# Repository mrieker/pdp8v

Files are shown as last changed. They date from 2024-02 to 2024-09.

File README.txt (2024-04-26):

Vacuum tube implementation of PDP-8/V using a Raspberry PI for memory and I/O devices.

Website:  https://www.outerworldapps.com/pdp8v

To generate PCBs (can be run from a PC or a RasPI):
    cd netgen
    make
    cd ../modules
    make   << generates unrouted ACL, ALU, MA, PC, RPI, SEQ boards

    open each of the above in its directory in the kicads directory
    ... and route route route!

Or use these routed PCBs that match this rev:
    https://www.outerworldapps.com/pdp8v/acl-2024-04-15.tgz
    https://www.outerworldapps.com/pdp8v/alu-2024-04-15.tgz
    https://www.outerworldapps.com/pdp8v/ma-2024-04-15.tgz
    https://www.outerworldapps.com/pdp8v/pc-2024-04-15.tgz
    https://www.outerworldapps.com/pdp8v/rpi-2024-04-15.tgz
    https://www.outerworldapps.com/pdp8v/seq-2024-04-15.tgz

To run a PDP-8 program (from a RasPI plugged into RPI board):
    cd driver
    make raspictl.`uname -m`
    ./raspictl -binloader <name-of-some-bin-format-file>
            or -rimloader <name-of-some-rim-format-file>

See the website for other options for running programs.

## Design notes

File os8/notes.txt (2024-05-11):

run with ./ock-boot.sh [-csrclib]

.R RESORC
*/X
SYS,DSK,RKA0,RKB0,RKA1,RKB1,RKA2,RKB2,TTY,LPT,DTA0,DTA1,PTP,PTR

*/E

89 FILES IN 1429 BLOCKS USING 3 SEGMENTS
1763 FREE BLOCKS

#  NAME TYPE MODE SIZ BLK KIND U V ENT USER
01 SYS  RK8E RWF 3248 SYS      0 C  07
02 DSK  RK8E RWF 3248 SYS      1 C  21
03 RKA0 RK8E RWF 3248 SYS      0 C  07
04 RKB0 RK8E RWF 3248 SYS      1 C  21
05 RKA1 RK8E RWF 3248 16  RK05 1 A  22
06 RKB1 RK8E RWF 3248 16  RK05 1 A  23
07 RKA2 RK8E RWF 3248 16  RK05 2 A  24
10 RKB2 RK8E RWF 3248 16  RK05 2 A  25
11 TTY  TTY  RW       17+ KL8E   E 176
12 LPT  LPTR W        20  LPSV   C  05
13 DTA0 TC08 RWF  737 21       0 A  10
14 DTA1 TC08 RWF  737 21       1 A  11
15 PTP  PTP  W        22  PT8E   A  00
16 PTR  PTR  R        22  PT8E   A 112

FREE DEVICE SLOTS: 01,  FREE BLOCK SLOTS: 03
OS/8 V3T

*^C

.

accessing drive 0:

    DIR RKA0:   << same as DIR SYS:
    DIR RKB0:   << same as DIR

accessing drive 1:

    ZERO RKA1:
    ZERO RKB1:

    DIR RKA1:
    DIR RKB1:

copy file to paper tape:

    raspictl> iodev ptape load punch x.x

    .COPY PTP:<RKA2:FILE.NM

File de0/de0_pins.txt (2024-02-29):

    GPIO-0/JP1

    GPIO_0_IN0  A8   1   2  D3  GPIO_0_0
    GPIO_0_IN1  B8   3   4  C3  GPIO_0_1
    GPIO_0_2    A2   5   6  A3  GPIO_0_3
    GPIO_0_4    B3   7   8  B4  GPIO_0_5
    GPIO_0_6    A4   9  10  B5  GPIO_0_7
    VCC_SYS         11  12      GND
    GPIO_0_8    A5  13  14  D5  GPIO_0_9
    GPIO_0_10   B6  15  16  A6  GPIO_0_11
    GPIO_0_12   B7  17  18  D6  GPIO_0_13
    GPIO_0_14   A7  19  20  C6  GPIO_0_15
    GPIO_0_16   C8  21  22  E6  GPIO_0_17
    GPIO_0_18   E7  23  24  D8  GPIO_0_19
    GPIO_0_20   E8  25  26  F8  GPIO_0_21
    GPIO_0_22   F9  27  28  E9  GPIO_0_23
    VCC_3P3         29  30      GND
    GPIO_0_24   C9  31  32  D9  GPIO_0_25
    GPIO_0_26   E11 33  34  E11 GPIO_0_27
    GPIO_0_28   C11 35  36  B11 GPIO_0_29
    GPIO_0_30   A12 37  38  D11 GPIO_0_31
    GPIO_0_32   D12 39  40  B12 GPIO_0_33

DE0-LEDS

    D34 GPIO_0_33                               D16 GPIO_0_32
                    D33 GPIO_0_31                               D15 GPIO_0_30
    D32 GPIO_0_29                               D14 GPIO_0_28
                    D31 GPIO_0_27                               D13 GPIO_0_26
    D30 GPIO_0_25                               D12 GPIO_0_24

                    D29 GPIO_0_23                               D11 GPIO_0_22
    D28 GPIO_0_21                               D10 GPIO_0_20
                    D27 GPIO_0_19                               D9  GPIO_0_18
    D26 GPIO_0_17                               D8  GPIO_0_16
                    D25 GPIO_0_15                               D7  GPIO_0_14
    D24 GPIO_0_13                               D6  GPIO_0_12
                    D23 GPIO_0_11                               D5  GPIO_0_10
    D22 GPIO_0_9                                D4  GPIO_0_8

                    D21 GPIO_0_7                                D3  GPIO_0_6
    D20 GPIO_0_5                                D2  GPIO_0_4
                    D19 GPIO_0_3                                D1  GPIO_0_2
    D18 GPIO_0_1
                    D17 GPIO_0_0

                          GPIO-1/JP2                                                RASPI
     raspi    de0                         de0      raspi            de0      raspi           raspi    de0
            GPIO_1_IN0  T9   1   2  F13 GPIO_1_0  GPIO_26         GPIO_1_2  GPIO_21 40  39  GND
            GPIO_1_IN1  R9   3   4  T15 GPIO_1_1  GPIO_19         GPIO_1_4  GPIO_20 38  37  GPIO_26 GPIO_1_0
    GPIO_21 GPIO_1_2    T14  5   6  T13 GPIO_1_3  GPIO_13         GPIO_1_6  GPIO_16 36  35  GPIO_19 GPIO_1_1
    GPIO_20 GPIO_1_4    R13  7   8  T12 GPIO_1_5  GPIO_6                    GND     34  33  GPIO_13 GPIO_1_3
    GPIO_16 GPIO_1_6    R12  9  10  T11 GPIO_1_7  GPIO_5          GPIO_1_8  GPIO_12 32  31  GPIO_6  GPIO_1_5
            VCC_SYS         11  12      GND                                 GND     30  29  GPIO_5  GPIO_1_7
    GPIO_12 GPIO_1_8    T10 13  14  R11 GPIO_1_9                            ID_SC   28  27  ID_SD
    GPIO_7  GPIO_1_10   P11 15  16  R10 GPIO_1_11                 GPIO_1_10 GPIO_7  26  25  GND
    GPIO_8  GPIO_1_12   N12 17  18  P9  GPIO_1_13 GPIO_11         GPIO_1_12 GPIO_8  24  23  GPIO_11 GPIO_1_13
    GPIO_25 GPIO_1_14   N9  19  20  N11 GPIO_1_15 GPIO_9          GPIO_1_14 GPIO_25 22  21  GPIO_9  GPIO_1_15
            GPIO_1_16   L16 21  22  K16 GPIO_1_17 GPIO_10                   GND     20  19  GPIO_10 GPIO_1_17
    GPIO_24 GPIO_1_18   R16 23  24  L15 GPIO_1_19 GPIO_22         GPIO_1_18 GPIO_24 18  17  3.3V
    GPIO_23 GPIO_1_20   P15 25  26  P16 GPIO_1_21 GPIO_27         GPIO_1_20 GPIO_23 16  15  GPIO_22 GPIO_1_19
            GPIO_1_22   R14 27  28  N16 GPIO_1_23 GPIO_17                   GND     14  13  GPIO_27 GPIO_1_21
            VCC_3P3         29  30      GND                       GPIO_1_24 GPIO_18 12  11  GPIO_17 GPIO_1_23
    GPIO_18 GPIO_1_24   N15 31  32  P14 GPIO_1_25                 GPIO_1_26 GPIO_15 10   9  GND
    GPIO_15 GPIO_1_26   L14 33  34  N14 GPIO_1_27 GPIO_4          GPIO_1_28 GPIO_14  8   7  GPIO_4  GPIO_1_27
    GPIO_14 GPIO_1_28   M10 35  36  L13 GPIO_1_29 GPIO_3                    GND      6   5  GPIO_3  GPIO_1_29
            GPIO_1_30   J16 37  38  K15 GPIO_1_31 GPIO_2                    5V       4   3  GPIO_2  GPIO_1_31
            GPIO_1_32   J13 39  40  J14 GPIO_1_33                           5V       2   1  3.3V

                                         CLK    CS   RES   GND   3.3
                                           *     *     *     *     *
                                           6     7     8     9    10

                                                    OLIMEX
                                                  ENC28J60-H

                                           5     4     3     2     1
                                           *     *     *     *     *
                                         INT   WOL    SO    SI   SCK

                                      PIN_D9   E10   B11   D11   B12
                                    GPIO_025   027   029   031   033
                GND                GND   INT   CLK    CS   RES    COMRCV
 2               12                 30    32    34    36    38    40
 *                *                  *     *     *     *     *     *

 *                *                  *     *     *     *     *     *
 1               11                 29    31    33    35    37    39
                +5V               +3.3   WOL    SO    SI   SCK    COMXMT
                                    GPIO_024   026   028   030   032
                                      PIN_C9   E11   C11   A12   D12

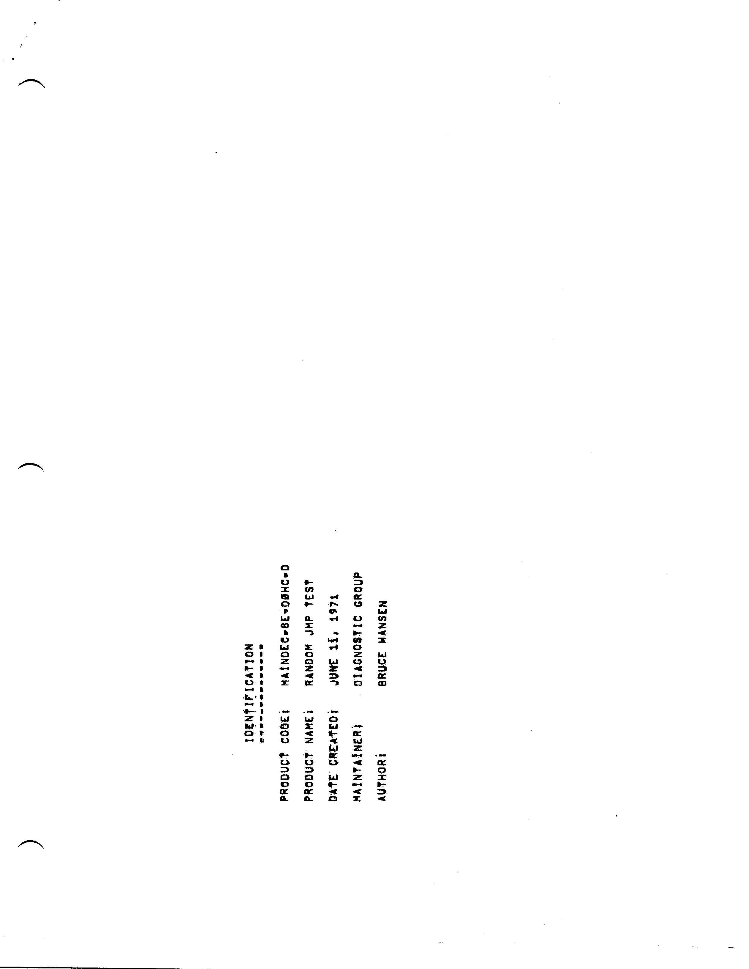
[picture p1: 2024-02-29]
maindec/docs/d0hc-d.tif

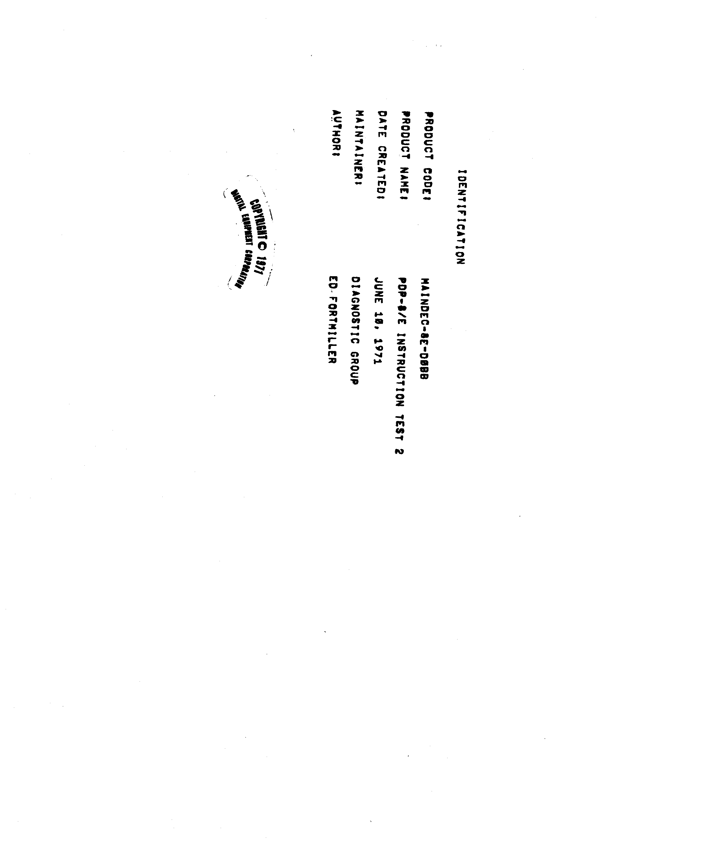
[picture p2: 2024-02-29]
maindec/docs/d0bb.tif

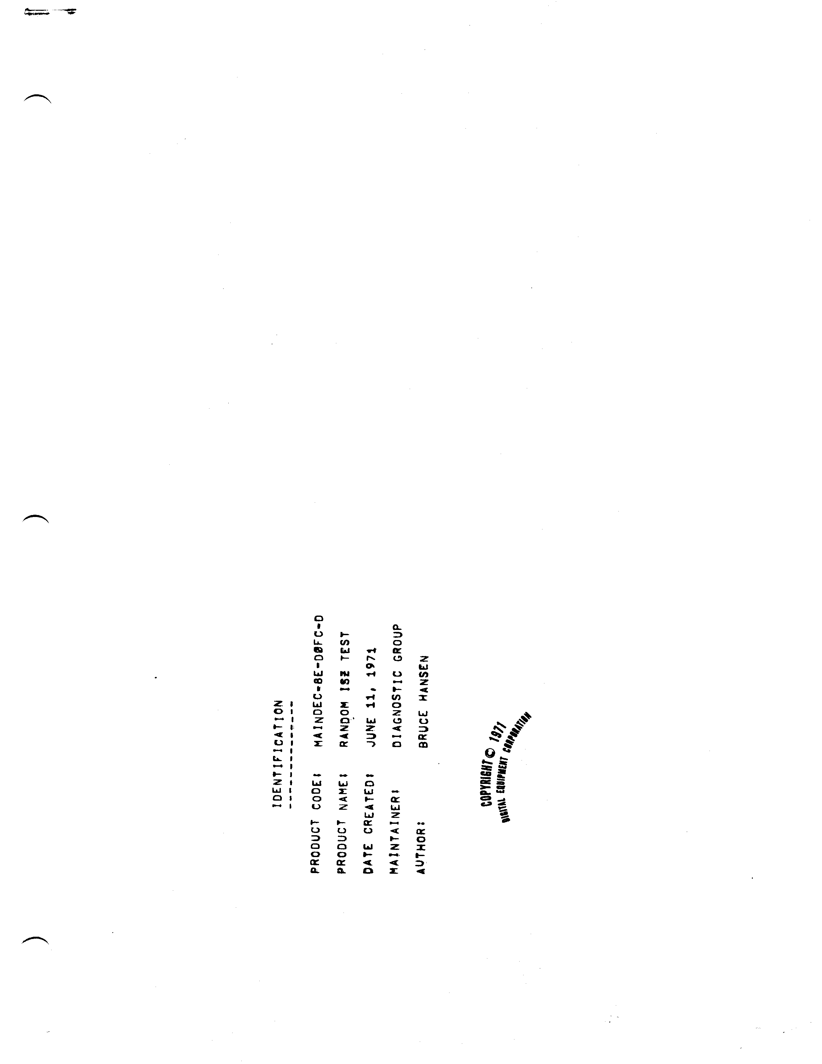
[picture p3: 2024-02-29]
maindec/docs/d0fc-d.tif

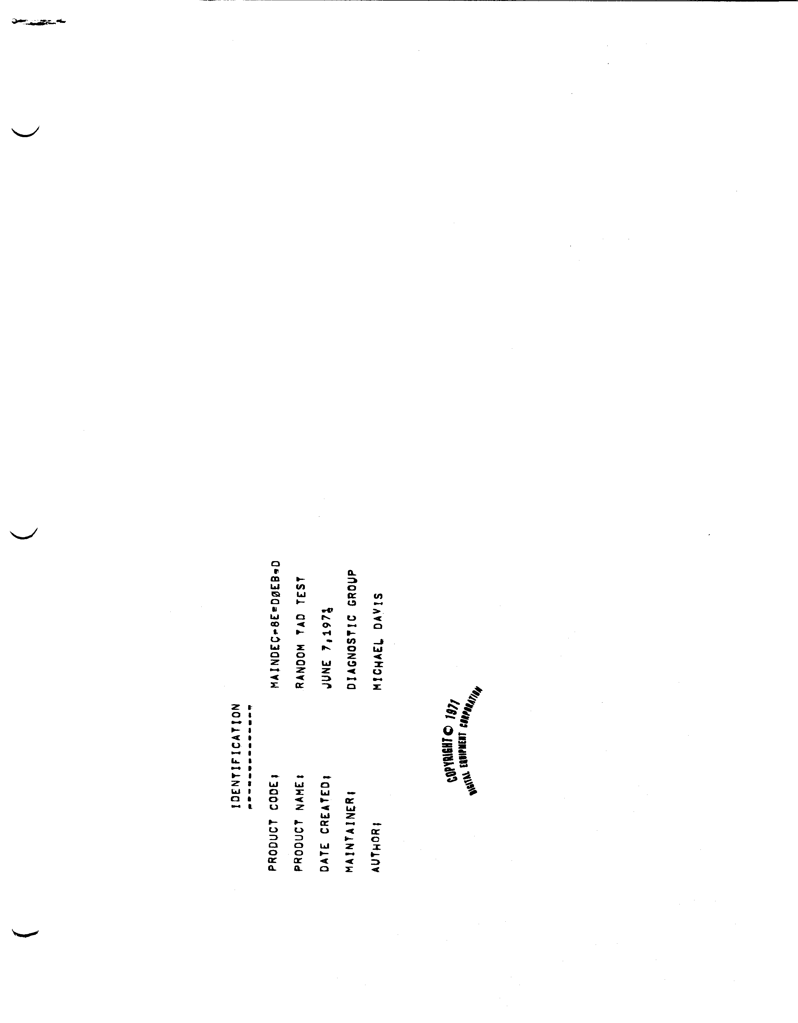
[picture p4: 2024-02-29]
maindec/docs/d0eb-d.tif

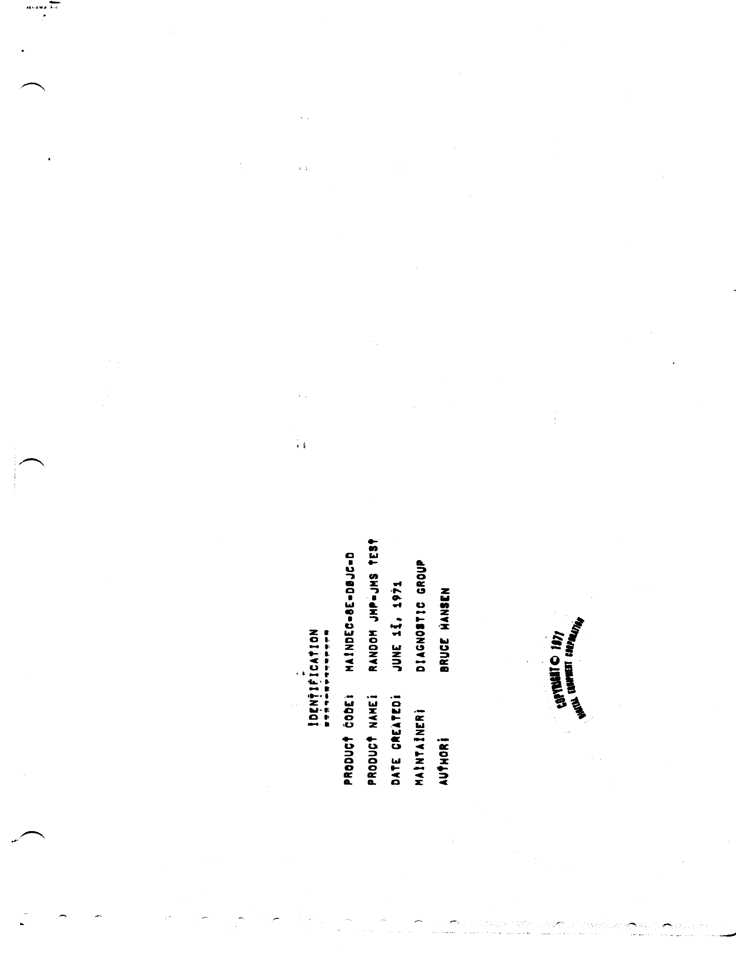
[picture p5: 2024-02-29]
maindec/docs/d0jc-d.tif

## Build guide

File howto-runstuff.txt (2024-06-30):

Add -csrclib option to any of the below to run on PC gate-level simulator
Add -zynqlib option to any of the below to run on Zynq gate-level simulator
By default, it must be run on a RasPI plugged into full tube board set

Random instruction test:
    cd driver
    ./raspictl -randmem -mintimes

Edusystem-20 Basic:
    cd edu20c
    ./runpt.sh
    ...then telnet raspi 12303 to access first tty
                         12340 to access second tty
                         12342 to access third tty
                         12344 to access fourth tty
                         12346 to access fifth tty

Focal-69:
    cd focal
    ./focal69.sh
    ...then telnet raspi 12303 to access tty

OS/8:
    cd os8
    ./ock-boot.sh
    ...then telnet raspi 12303 to access tty

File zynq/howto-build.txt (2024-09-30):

to build zynq zturn:

    ./makemodv.sh   ...create verilog equivalent of tube boards
    ./makentov.sh   ...adds nto counters (number of tubes on) to verilog

    build bitstream file with vivado2018.3 or try script ./makebitfile.sh
        ...creates file pdp8v.runs/impl_1/myboard_wrapper.bit

    create BOOT.BIN file with ./makebootbin.sh
        this requires ~/MYIR_HW contain directories
            petadevel   ...which contains petadevel/settings.sh
            petakernl   ...which contains petakernl/zturn/images/linux

to run it:
    cd pdp8v/driver
    ./raspictl -zynqlib -randmem -mintimes

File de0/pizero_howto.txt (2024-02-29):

plug USB cable into center-most connector
give it a few seconds to boot

on homepc, do ifconfig
look for device enp0s29u1u7i1 or similar
do ifconfig enp0s29u1u7i1 192.168.5.1
do ssh pi@192.168.5.2

seems the ifconfig on homepc drops ip address without notice
so put the ifconfig in a loop script one a second

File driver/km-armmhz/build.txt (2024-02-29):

# make sure running latest kernel so installing headers will match version
apt-get update
apt-get upgrade

# install latest headers
apt-get install raspberrypi-kernel-headers

# compile and load
make
insmod armmhz.ko

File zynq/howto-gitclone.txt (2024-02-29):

made from pdp8v.tcl
  file->project->write tcl
  default options (only 'copy sources to new project' checked)

assumes vivado 2023.2 is started from the project directory when tcl file is created,
eg, vivado pdp8v.xpr

when cloning:
 1) start vivado from the project directory and 'source pdp8v.tcl' script
    - it creates a subdirectory with copy of all the source files plus lots of puque
    - tcl error is ok: 'ERROR: [Common 17-69] Command failed: Invalid constraints filename specified'
 2) shut down vivado
 3) delete files from the project directory:
      rm -rf NA pdp8v.srcs vivado.* .Xil
 4) move all files from subdirectory to project directory & delete subdirectory:
      mv pdp8v/* .
      rmdir pdp8v
 5) the dumbbell vivado sometimes moves files, eg, from sources_1/new to sources_1/imported/new
      so git might have to be updated with the moved files
 6) restart vivado from project directory:
      vivado pdp8v.xpr
 7) re-generate the pdp8v.tcl script to reflect the moved files and update it in git
 8) it takes extra time to build (generate bitstream) first time

use makebootbin.sh to create BOOT.BIN file and copy to zturn's /boot/ directory
to test, from the zturn:
  cd nfs/pdp8/driver
  ./raspictl -randmem -printinstr -zynqlib

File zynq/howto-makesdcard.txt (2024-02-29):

how to make an bootable SD card:

 1) copy bootable raspi SD card
 2) re-init boot partition (keeping it FAT)
 3) copy BOOT.BIN, image.ub, and make an empty config.txt

or starting with bootable zynq SD card:

 1) copy root filesystem from raspi card to zynq card

either way then:

 1) modify /etc/fstab to mount the correct partitions (UUIDs might be different)

  proc            /proc  proc  defaults          0  0
  /dev/mmcblk0p1  /boot  vfat  defaults          0  2
  /dev/mmcblk0p2  /      ext4  defaults,noatime  0  1

 2) put in zynq and reboot
    serial port console comes up as 9600 baud

 3) maybe unlock root account by setting password with passwd command

 4) update /etc/hostname, /etc/hosts and /etc/dhcpcd.conf

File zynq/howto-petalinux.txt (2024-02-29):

##########################
#   build linux kernel   #
##########################

# https://www.instructables.com/Getting-Started-With-PetaLinux/

apt install tofrodos iproute gawk gcc git-core make net-tools ncurses-dev libncurses5-dev tftpd-hpa zlib1g-dev flex bison lib32z1 lib32ncurses5 lib32stdc++6 libselinux1
apt install build-essential
apt install chrpath socat autoconf libtool texinfo gcc-multilib
apt install libsdl1.2-dev libglib2.0-dev
apt install openssl-dev
apt install libssl-dev
apt install openssl
apt install zlib1g:i386

dpkg-reconfigure dash

mkdir petadevel
/tools/Xilinx/Downloads/petalinux-v2018.3-final-installer.run petadevel

source petadevel/settings.sh
source /tools/Xilinx/Vivado/2018.3/settings64.sh

mkdir petakernl
cd petakernl
petalinux-create -t project -s ../zturn_7z020_hdmi.bsp
cd zturn
petalinux-config    1m35    << accept all defaults

petalinux-config -c kernel
    Device Drivers --->
        DMA Engine Support --->
            Xilinx DMA Engines [off]
            Xilinx AXI DMAS Engine [off]
petalinux-build     3m6     << let it fail to build vdmafb.c

cd build/tmp/work-shared/plnx-zynq7/kernel-source
  patch -p1 < ~/MYIR_HW/vdmahdmi.patch
    to drivers to disable VDMA and HDMI

    - unpatched xilinx_vtc.c 20094 bytes
        patched xilinx_vtc.c 19220 bytes

cc ../../../../..
petalinux-build     1m55    << it should succeed

petalinux-package --boot --force --fsbl ./images/linux/zynq_fsbl.elf --fpga ./images/linux/system.bit --u-boot
  copy images/linux/BOOT.BIN,image.ub to /boot/ on sdcard

#######################################
#   build BOOT.BIN with a .bit file   #
#######################################

# creates BOOT.BIN - can be run chrooted to the ubu1604 disk
#  - can use any .bit file
(do the above 2 source commands)
petalinux-package --boot --force --fsbl ./images/linux/zynq_fsbl.elf --fpga ./images/linux/system.bit --u-boot

#################################################
#   copying raspi linux rootfs to zynq rootfs   #
#################################################

copy homepi rootfs to zynq rootfs (rsync -aHxv)
- change ip address to 192.168.1.19
  get rid of vpn stuff
  update fstab entries
  delete homebackups
  empty out crontab
  change /etc/hostname to zturn

uname -r = 4.14.0-xilinx-v2018.3

kernel source is in test01/zturn/build/tmp/work-shared/plnx-zynq7/kernel-source
  rsync -av test01/zturn/build/tmp/work-shared/plnx-zynq7/kernel-source/ root@zturn:/usr/src/linux-headers-4.14.0-xilinx-v2018.3
  rsync -av test01/zturn/build/tmp/work-shared/plnx-zynq7/kernel-build-artifacts/ root@zturn:/usr/src/linux-headers-4.14.0-xilinx-v2018.3

then on zturn as root:
  ln -s /usr/src/linux-headers-4.14.0-xilinx-v2018.3 /lib/modules/4.14.0-xilinx-v2018.3/build

  cd /usr/src/linux-headers-4.14.0-xilinx-v2018.3
  make oldconfig && make prepare
  make modules_prepare

##############################
#   create a Vivado project  #
##############################

Use Z-turnBoard_Tutorial_Book.pdf
    - make sure board_files/zturn-7z020 is in place in vivado tree
    - in left column, "Create Block Design"
    - add ZYNQ7 Processing System
    - do "Run Block Automation" to define and connect DDR, FIXED_IO ports
    - interconnect clocks FCLK_CLK0 -> M_AXI_GP0_ACLK, S_AXI_HP0_ACLK
    - add any Verilog/VHDL files & add as modules to block diagram
    - create hardware wrapper
        "Sources" tab
        right-click the .bd file
        select "Create HDL Wrapper"
        "Let Vivado manage..."
        OK

    - Run Synthesis, but then do "Open Synthesized Design"
        - Window -> I/O Ports
        - Scalar ports
        - make pin assignments
        - click save (floppy) button in upper left to save as constraints file

    - Run Synthesis again to use new pin assignments
    - Run Implementation
    - Generate Bitstream

create a new BOOT.BIN -
    source both.si
    cd test01/zturn
    petalinux-package --boot --force --fsbl ./images/linux/zynq_fsbl.elf --fpga ***BITFILE***.bit --u-boot
...get BOOT.BIN from images/linux

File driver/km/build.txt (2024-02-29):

raspberry pi:

    # make sure running latest kernel so installing headers will match version
    apt-get update
    apt-get upgrade

    # install latest headers
    apt-get install raspberrypi-kernel-headers

zync zturn:

    build petalinux on a PC

        mkdir petadevel
        /tools/Xilinx/Downloads/petalinux-v2018.3-final-installer.run petadevel
        source petadevel/settings.sh
        source /tools/Xilinx/Vivado/2018.3/settings64.sh
        mkdir petakernl
        cd petakernl
        petalinux-create -t project -s ../zturn_7z020_hdmi.bsp
        cd zturn
        petalinux-config        << accept all defaults
        petalinux-build

        source is in petakernl/zturn/build/tmp/work-shared/plnx-zynq7/kernel-source
        copy it to zturn:/usr/src/linux-headers-4.14.0-xilinx-v2018.3

    also need softlink on zturn:
        ln -s /usr/src/linux-headers-4.14.0-xilinx-v2018.3 /lib/modules/4.14.0-xilinx-v2018.3/build

    build the kernel on zturn:
        cd /usr/src/linux-headers-4.14.0-xilinx-v2018.3
        make oldconfig && make prepare
        make modules_prepare

compile and load this module:

    make
    insmod enabtsc.ko

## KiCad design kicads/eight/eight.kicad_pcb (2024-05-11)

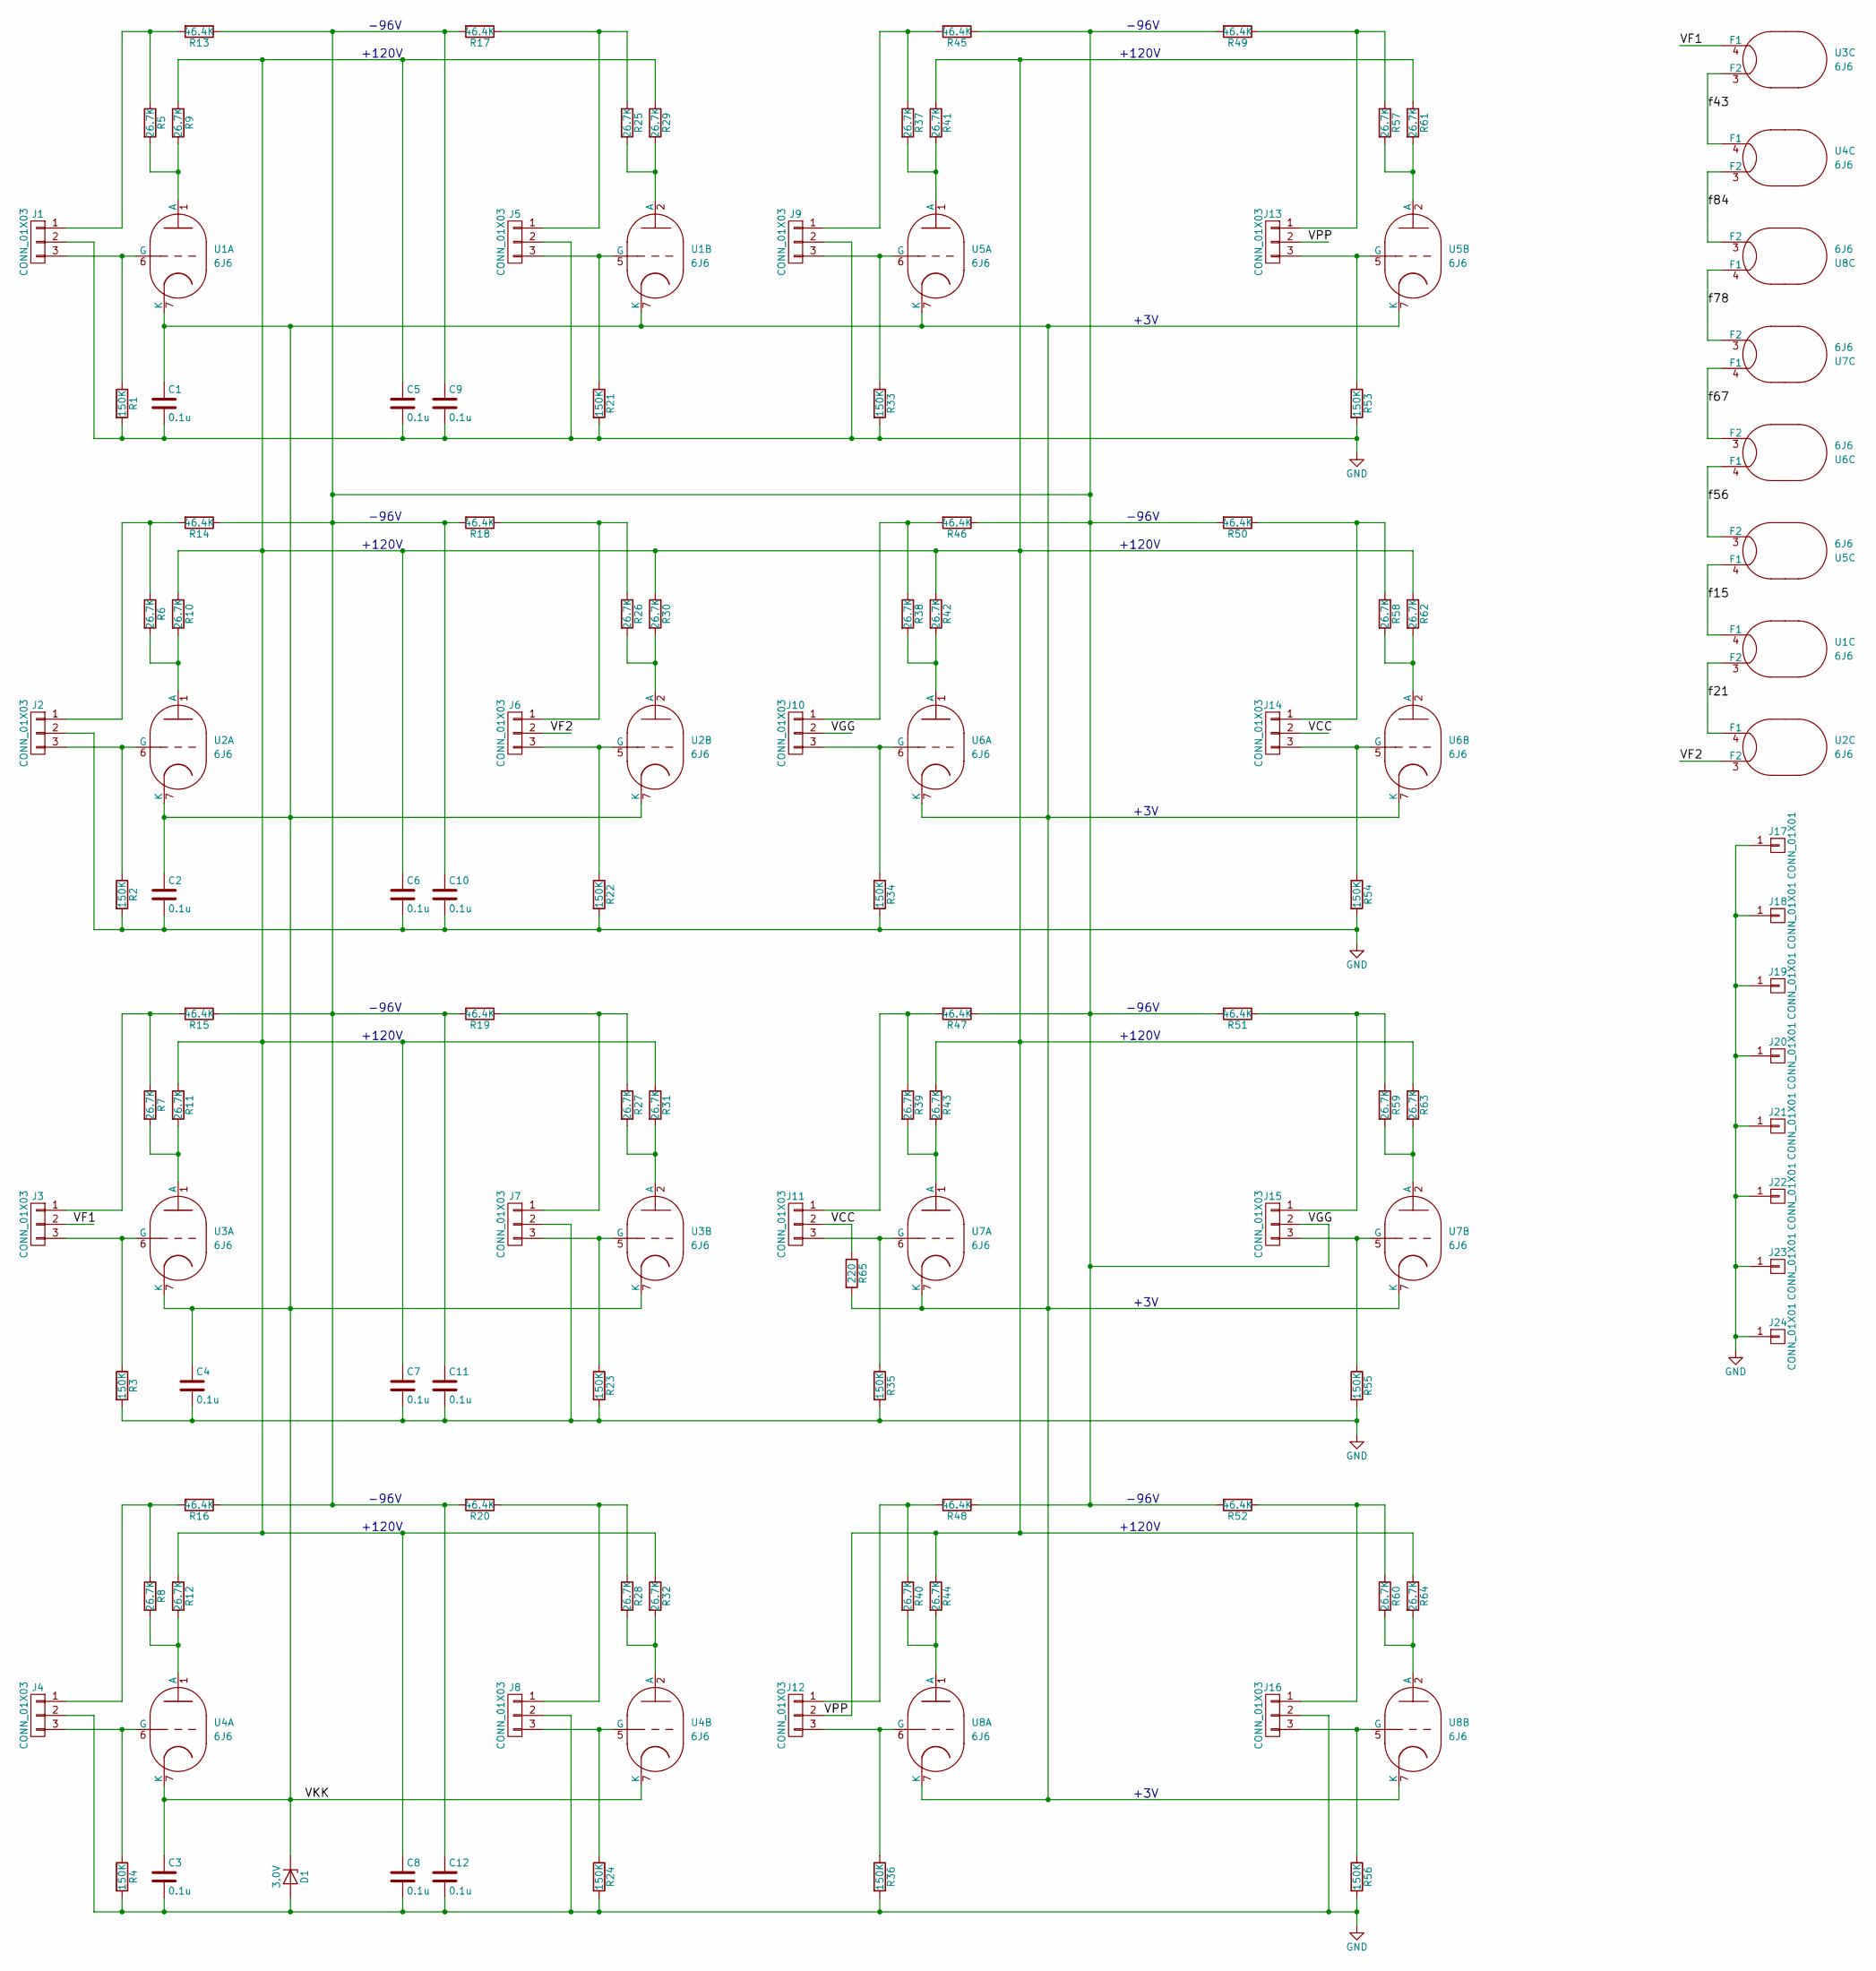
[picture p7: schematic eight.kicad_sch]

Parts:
C1, C2, C3, C4, C5, C6, C7, C8, C9, C10, C11, C12: 0.1u; C_Axial_0.1uF
D1: 3.0V; D_DO-35_SOD27_P7.62mm_Horizontal
J1, J2, J3, J4, J5, J6, J7, J8, J9, J10, J11, J12, J13, J14, J15, J16: CONN_01X03; Pin_Header_Straight_1x03_Pitch2.54mm
J17, J18, J19, J20, J21, J22, J23, J24: CONN_01X01; Pin_Header_Straight_1x01_Pitch2.54mm
R1, R2, R3, R4, R21, R22, R23, R24, R33, R34, R35, R36, R53, R54, R55, R56: 150K; R_Axial_QtrWatt
R5, R6, R7, R8, R9, R10, R11, R12, R25, R26, R27, R28, R29, R30, R31, R32, R37, R38, R39, R40, R41, R42, R43, R44, R57, R58, R59, R60, R61, R62, R63, R64: 26.7K; R_Axial_QtrWatt
R13, R14, R15, R16, R17, R18, R19, R20, R45, R46, R47, R48, R49, R50, R51, R52: 46.4K; R_Axial_QtrWatt
R65: 220; R_Axial_QtrWatt
U1, U2, U3, U4, U5, U6, U7, U8: 6J6; B7G-0.7dia

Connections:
/VCC: J11.2, J14.2, R65.1
/VF1: J3.2, U3.4 (F1)
/VF2: J6.2, U2.3 (F2)
/VGG: C9.1, C10.1, C11.1, C12.1, J10.2, J15.2, R13.1, R14.1, R15.1, R16.1, R17.2, R18.2, R19.2, R20.2, R45.1, R46.1, R47.1, R48.1, R49.2, R50.2, R51.2, R52.2
/VKK: C1.1, C2.1, C3.1, C4.1, D1.1 (K), R65.2, U1.7 (K), U2.7 (K), U3.7 (K), U4.7 (K), U5.7 (K), U6.7 (K), U7.7 (K), U8.7 (K)
/VPP: C5.1, C6.1, C7.1, C8.1, J12.2, J13.2, R9.1, R10.1, R11.1, R12.1, R29.1, R30.1, R31.1, R32.1, R41.1, R42.1, R43.1, R44.1, R61.1, R62.1, R63.1, R64.1
/f15: U1.4 (F1), U5.4 (F1)
/f21: U1.3 (F2), U2.4 (F1)
/f43: U3.3 (F2), U4.4 (F1)
/f56: U5.3 (F2), U6.4 (F1)
/f67: U6.3 (F2), U7.4 (F1)
/f78: U7.3 (F2), U8.4 (F1)
/f84: U4.3 (F2), U8.3 (F2)
GND: C1.2, C2.2, C3.2, C4.2, C5.2, C6.2, C7.2, C8.2, C9.2, C10.2, C11.2, C12.2, D1.2 (A), J1.2, J2.2, J4.2, J5.2, J7.2, J8.2, J9.2, J16.2, J17.1, J18.1, J19.1, J20.1, J21.1, J22.1, J23.1, J24.1, R1.2, R2.2, R3.2, R4.2, R21.2, R22.2, R23.2, R24.2, R33.2, R34.2, R35.2, R36.2, R53.2, R54.2, R55.2, R56.2
unnamed: J1.1, R5.1, R13.2
unnamed: J1.3, R1.1, U1.6 (G)
unnamed: J2.1, R6.1, R14.2
unnamed: J2.3, R2.1, U2.6 (G)
unnamed: J3.1, R7.1, R15.2
unnamed: J3.3, R3.1, U3.6 (G)
unnamed: J4.1, R8.1, R16.2
unnamed: J4.3, R4.1, U4.6 (G)
unnamed: J5.1, R17.1, R25.1
unnamed: J5.3, R21.1, U1.5 (G)
unnamed: J6.1, R18.1, R26.1
unnamed: J6.3, R22.1, U2.5 (G)
unnamed: J7.1, R19.1, R27.1
unnamed: J7.3, R23.1, U3.5 (G)
unnamed: J8.1, R20.1, R28.1
unnamed: J8.3, R24.1, U4.5 (G)
unnamed: J9.1, R37.1, R45.2
unnamed: J9.3, R33.1, U5.6 (G)
unnamed: J10.1, R38.1, R46.2
unnamed: J10.3, R34.1, U6.6 (G)
unnamed: J11.1, R39.1, R47.2
unnamed: J11.3, R35.1, U7.6 (G)
unnamed: J12.1, R40.1, R48.2
unnamed: J12.3, R36.1, U8.6 (G)
unnamed: J13.1, R49.1, R57.1
unnamed: J13.3, R53.1, U5.5 (G)
unnamed: J14.1, R50.1, R58.1
unnamed: J14.3, R54.1, U6.5 (G)
unnamed: J15.1, R51.1, R59.1
unnamed: J15.3, R55.1, U7.5 (G)
unnamed: J16.1, R52.1, R60.1
unnamed: J16.3, R56.1, U8.5 (G)
unnamed: R5.2, R9.2, U1.1 (A)
unnamed: R25.2, R29.2, U1.2 (A)
unnamed: R6.2, R10.2, U2.1 (A)
unnamed: R26.2, R30.2, U2.2 (A)
unnamed: R7.2, R11.2, U3.1 (A)
unnamed: R27.2, R31.2, U3.2 (A)
unnamed: R8.2, R12.2, U4.1 (A)
unnamed: R28.2, R32.2, U4.2 (A)
unnamed: R37.2, R41.2, U5.1 (A)
unnamed: R57.2, R61.2, U5.2 (A)
unnamed: R38.2, R42.2, U6.1 (A)
unnamed: R58.2, R62.2, U6.2 (A)
unnamed: R39.2, R43.2, U7.1 (A)
unnamed: R59.2, R63.2, U7.2 (A)
unnamed: R40.2, R44.2, U8.1 (A)
unnamed: R60.2, R64.2, U8.2 (A)

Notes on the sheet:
-96V
+3V
+120V

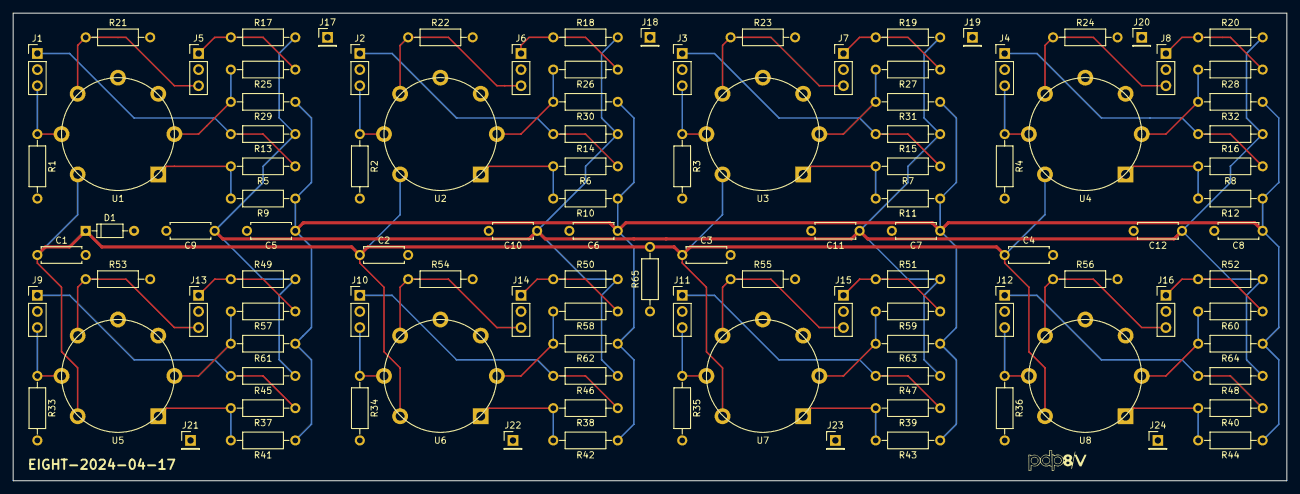
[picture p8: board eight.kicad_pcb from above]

Board: 4 copper layers, 200.7 x 73.7 mm, 110 parts (0 on the bottom side), 62 nets.

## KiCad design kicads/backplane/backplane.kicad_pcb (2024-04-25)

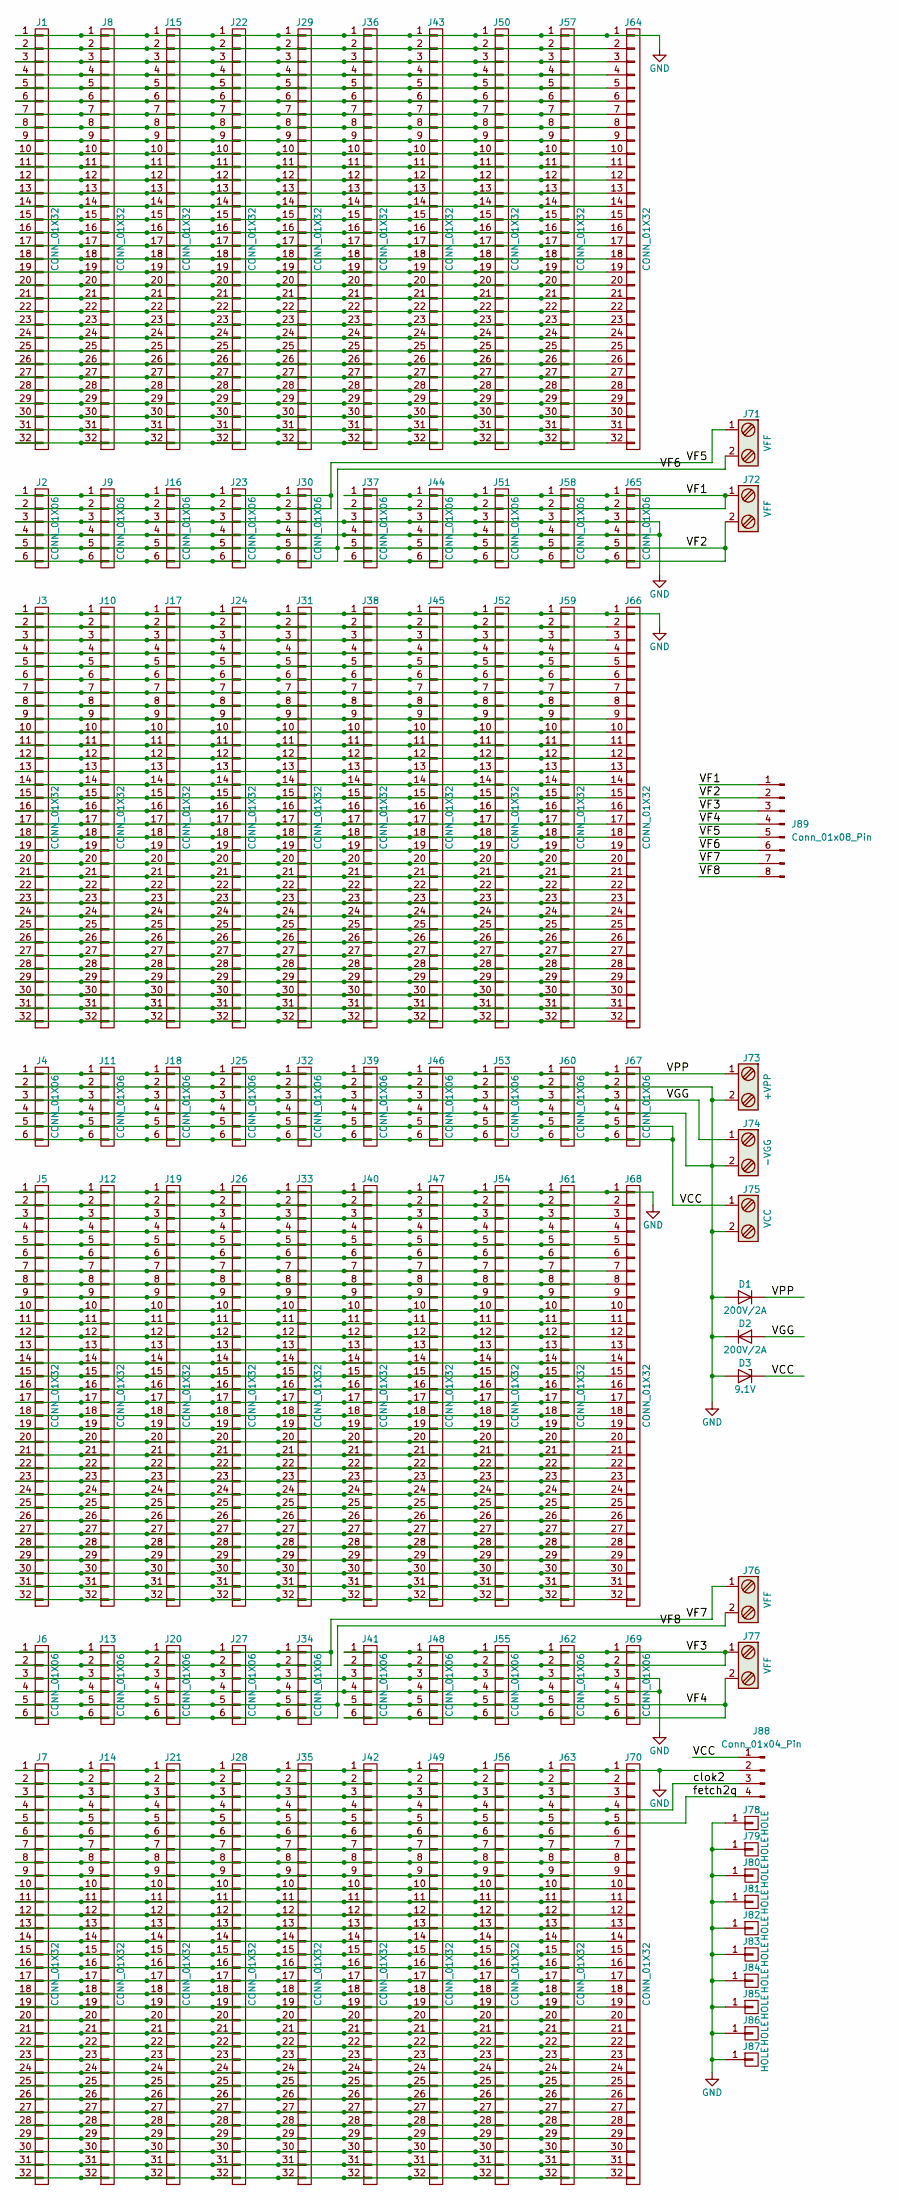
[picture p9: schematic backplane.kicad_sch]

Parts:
D1, D2: 200V/2A; D_DO-15_P12.70mm_Horizontal
D3: 9.1V; D_DO-15_P12.70mm_Horizontal
J1, J3, J5, J7, J8, J10, J12, J14, J15, J17, J19, J21, J22, J24, J26, J28, J29, J31, J33, J35, J36, J38, J40, J42, J43, J45, J47, J49, J50, J52, J54, J56, J57, J59, J61, J63, J64, J66, J68, J70: CONN_01X32; Pin_Header_Straight_1x32_Pitch2.54mm
J2, J4, J6, J9, J11, J13, J16, J18, J20, J23, J25, J27, J30, J32, J34, J37, J39, J41, J44, J46, J48, J51, J53, J55, J58, J60, J62, J65, J67, J69: CONN_01X06; Pin_Header_Straight_1x06_Pitch2.54mm
J71, J72, J76, J77: VFF; WireConnection_2.50mmDrill_LargePad
J73: +VPP; WireConnection_2.50mmDrill_LargePad
J74: -VGG; WireConnection_2.50mmDrill_LargePad
J75: VCC; WireConnection_2.50mmDrill_LargePad
J78, J79, J80, J81, J82, J83, J84, J85, J86, J87: HOLE; 1pin
J88: Conn_01x04_Pin; PinHeader_1x04_P2.54mm_Vertical
J89: Conn_01x08_Pin; PinHeader_1x08_P2.54mm_Vertical

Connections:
/VCC: D3.1 (K), J4.5, J4.6, J11.5, J11.6, J18.5, J18.6, J25.5, J25.6, J32.5, J32.6, J39.5, J39.6, J46.5, J46.6, J53.5, J53.6, J60.5, J60.6, J67.5, J67.6, J75.1, J88.1
/VF1: J37.1, J37.2, J44.1, J44.2, J51.1, J51.2, J58.1, J58.2, J65.1, J65.2, J72.1, J89.1
/VF2: J37.5, J37.6, J44.5, J44.6, J51.5, J51.6, J58.5, J58.6, J65.5, J65.6, J72.2, J89.2
/VF3: J41.1, J41.2, J48.1, J48.2, J55.1, J55.2, J62.1, J62.2, J69.1, J69.2, J77.1, J89.3
/VF4: J41.5, J41.6, J48.5, J48.6, J55.5, J55.6, J62.5, J62.6, J69.5, J69.6, J77.2, J89.4
/VF5: J2.1, J2.2, J9.1, J9.2, J16.1, J16.2, J23.1, J23.2, J30.1, J30.2, J71.1, J89.5
/VF6: J2.5, J2.6, J9.5, J9.6, J16.5, J16.6, J23.5, J23.6, J30.5, J30.6, J71.2, J89.6
/VF7: J6.1, J6.2, J13.1, J13.2, J20.1, J20.2, J27.1, J27.2, J34.1, J34.2, J76.1, J89.7
/VF8: J6.5, J6.6, J13.5, J13.6, J20.5, J20.6, J27.5, J27.6, J34.5, J34.6, J76.2, J89.8
/VGG: D2.2 (A), J4.3, J11.3, J18.3, J25.3, J32.3, J39.3, J46.3, J53.3, J60.3, J67.3, J74.1
/VPP: D1.1 (K), J4.1, J11.1, J18.1, J25.1, J32.1, J39.1, J46.1, J53.1, J60.1, J67.1, J73.1
/clok2: J7.4, J14.4, J21.4, J28.4, J35.4, J42.4, J49.4, J56.4, J63.4, J70.4, J88.3
/fetch2q: J7.5, J14.5, J21.5, J28.5, J35.5, J42.5, J49.5, J56.5, J63.5, J70.5, J88.4
GND: D1.2 (A), D2.1 (K), D3.2 (A), J1.1, J2.3, J2.4, J3.1, J4.2, J4.4, J5.1, J6.3, J6.4, J7.1, J8.1, J9.3, J9.4, J10.1, J11.2, J11.4, J12.1, J13.3, J13.4, J14.1, J15.1, J16.3, J16.4, J17.1, J18.2, J18.4, J19.1, J20.3, J20.4, J21.1, J22.1, J23.3, J23.4, J24.1, J25.2, J25.4, J26.1, J27.3, J27.4, J28.1, J29.1, J30.3, J30.4, J31.1, J32.2, J32.4, J33.1, J34.3, J34.4, J35.1, J36.1, J37.3, J37.4, J38.1, J39.2, J39.4, J40.1, J41.3, J41.4, J42.1, J43.1, J44.3, J44.4, J45.1, J46.2, J46.4, J47.1, J48.3, J48.4, J49.1, J50.1, J51.3, J51.4, J52.1, J53.2, J53.4, J54.1, J55.3, J55.4, J56.1, J57.1, J58.3, J58.4, J59.1, J60.2, J60.4, J61.1, J62.3, J62.4, J63.1, J64.1, J65.3, J65.4, J66.1, J67.2, J67.4, J68.1, J69.3, J69.4, J70.1, J73.2, J74.2, J75.2, J78.1, J79.1, J80.1, J81.1, J82.1, J83.1, J84.1, J85.1, J86.1, J87.1, J88.2
unnamed: J1.2, J8.2, J15.2, J22.2, J29.2, J36.2, J43.2, J50.2, J57.2, J64.2
unnamed: J1.3, J8.3, J15.3, J22.3, J29.3, J36.3, J43.3, J50.3, J57.3, J64.3
unnamed: J1.4, J8.4, J15.4, J22.4, J29.4, J36.4, J43.4, J50.4, J57.4, J64.4
unnamed: J1.5, J8.5, J15.5, J22.5, J29.5, J36.5, J43.5, J50.5, J57.5, J64.5
unnamed: J1.6, J8.6, J15.6, J22.6, J29.6, J36.6, J43.6, J50.6, J57.6, J64.6
unnamed: J1.7, J8.7, J15.7, J22.7, J29.7, J36.7, J43.7, J50.7, J57.7, J64.7
unnamed: J1.8, J8.8, J15.8, J22.8, J29.8, J36.8, J43.8, J50.8, J57.8, J64.8
unnamed: J1.9, J8.9, J15.9, J22.9, J29.9, J36.9, J43.9, J50.9, J57.9, J64.9
unnamed: J1.10, J8.10, J15.10, J22.10, J29.10, J36.10, J43.10, J50.10, J57.10, J64.10
unnamed: J1.11, J8.11, J15.11, J22.11, J29.11, J36.11, J43.11, J50.11, J57.11, J64.11
unnamed: J1.12, J8.12, J15.12, J22.12, J29.12, J36.12, J43.12, J50.12, J57.12, J64.12
unnamed: J1.13, J8.13, J15.13, J22.13, J29.13, J36.13, J43.13, J50.13, J57.13, J64.13
unnamed: J1.14, J8.14, J15.14, J22.14, J29.14, J36.14, J43.14, J50.14, J57.14, J64.14
unnamed: J1.15, J8.15, J15.15, J22.15, J29.15, J36.15, J43.15, J50.15, J57.15, J64.15
unnamed: J1.16, J8.16, J15.16, J22.16, J29.16, J36.16, J43.16, J50.16, J57.16, J64.16
unnamed: J1.17, J8.17, J15.17, J22.17, J29.17, J36.17, J43.17, J50.17, J57.17, J64.17
unnamed: J1.18, J8.18, J15.18, J22.18, J29.18, J36.18, J43.18, J50.18, J57.18, J64.18
unnamed: J1.19, J8.19, J15.19, J22.19, J29.19, J36.19, J43.19, J50.19, J57.19, J64.19
unnamed: J1.20, J8.20, J15.20, J22.20, J29.20, J36.20, J43.20, J50.20, J57.20, J64.20
unnamed: J1.21, J8.21, J15.21, J22.21, J29.21, J36.21, J43.21, J50.21, J57.21, J64.21
unnamed: J1.22, J8.22, J15.22, J22.22, J29.22, J36.22, J43.22, J50.22, J57.22, J64.22
unnamed: J1.23, J8.23, J15.23, J22.23, J29.23, J36.23, J43.23, J50.23, J57.23, J64.23
unnamed: J1.24, J8.24, J15.24, J22.24, J29.24, J36.24, J43.24, J50.24, J57.24, J64.24
unnamed: J1.25, J8.25, J15.25, J22.25, J29.25, J36.25, J43.25, J50.25, J57.25, J64.25
unnamed: J1.26, J8.26, J15.26, J22.26, J29.26, J36.26, J43.26, J50.26, J57.26, J64.26
unnamed: J1.27, J8.27, J15.27, J22.27, J29.27, J36.27, J43.27, J50.27, J57.27, J64.27
unnamed: J1.28, J8.28, J15.28, J22.28, J29.28, J36.28, J43.28, J50.28, J57.28, J64.28
unnamed: J1.29, J8.29, J15.29, J22.29, J29.29, J36.29, J43.29, J50.29, J57.29, J64.29
unnamed: J1.30, J8.30, J15.30, J22.30, J29.30, J36.30, J43.30, J50.30, J57.30, J64.30
unnamed: J1.31, J8.31, J15.31, J22.31, J29.31, J36.31, J43.31, J50.31, J57.31, J64.31
unnamed: J1.32, J8.32, J15.32, J22.32, J29.32, J36.32, J43.32, J50.32, J57.32, J64.32
unnamed: J3.2, J10.2, J17.2, J24.2, J31.2, J38.2, J45.2, J52.2, J59.2, J66.2
unnamed: J3.3, J10.3, J17.3, J24.3, J31.3, J38.3, J45.3, J52.3, J59.3, J66.3
unnamed: J3.4, J10.4, J17.4, J24.4, J31.4, J38.4, J45.4, J52.4, J59.4, J66.4
unnamed: J3.5, J10.5, J17.5, J24.5, J31.5, J38.5, J45.5, J52.5, J59.5, J66.5
unnamed: J3.6, J10.6, J17.6, J24.6, J31.6, J38.6, J45.6, J52.6, J59.6, J66.6
unnamed: J3.7, J10.7, J17.7, J24.7, J31.7, J38.7, J45.7, J52.7, J59.7, J66.7
unnamed: J3.8, J10.8, J17.8, J24.8, J31.8, J38.8, J45.8, J52.8, J59.8, J66.8
unnamed: J3.9, J10.9, J17.9, J24.9, J31.9, J38.9, J45.9, J52.9, J59.9, J66.9
unnamed: J3.10, J10.10, J17.10, J24.10, J31.10, J38.10, J45.10, J52.10, J59.10, J66.10
unnamed: J3.11, J10.11, J17.11, J24.11, J31.11, J38.11, J45.11, J52.11, J59.11, J66.11
unnamed: J3.12, J10.12, J17.12, J24.12, J31.12, J38.12, J45.12, J52.12, J59.12, J66.12
unnamed: J3.13, J10.13, J17.13, J24.13, J31.13, J38.13, J45.13, J52.13, J59.13, J66.13
unnamed: J3.14, J10.14, J17.14, J24.14, J31.14, J38.14, J45.14, J52.14, J59.14, J66.14
unnamed: J3.15, J10.15, J17.15, J24.15, J31.15, J38.15, J45.15, J52.15, J59.15, J66.15
unnamed: J3.16, J10.16, J17.16, J24.16, J31.16, J38.16, J45.16, J52.16, J59.16, J66.16
unnamed: J3.17, J10.17, J17.17, J24.17, J31.17, J38.17, J45.17, J52.17, J59.17, J66.17
unnamed: J3.18, J10.18, J17.18, J24.18, J31.18, J38.18, J45.18, J52.18, J59.18, J66.18
unnamed: J3.19, J10.19, J17.19, J24.19, J31.19, J38.19, J45.19, J52.19, J59.19, J66.19
unnamed: J3.20, J10.20, J17.20, J24.20, J31.20, J38.20, J45.20, J52.20, J59.20, J66.20
unnamed: J3.21, J10.21, J17.21, J24.21, J31.21, J38.21, J45.21, J52.21, J59.21, J66.21
unnamed: J3.22, J10.22, J17.22, J24.22, J31.22, J38.22, J45.22, J52.22, J59.22, J66.22
unnamed: J3.23, J10.23, J17.23, J24.23, J31.23, J38.23, J45.23, J52.23, J59.23, J66.23
unnamed: J3.24, J10.24, J17.24, J24.24, J31.24, J38.24, J45.24, J52.24, J59.24, J66.24
unnamed: J3.25, J10.25, J17.25, J24.25, J31.25, J38.25, J45.25, J52.25, J59.25, J66.25
unnamed: J3.26, J10.26, J17.26, J24.26, J31.26, J38.26, J45.26, J52.26, J59.26, J66.26
unnamed: J3.27, J10.27, J17.27, J24.27, J31.27, J38.27, J45.27, J52.27, J59.27, J66.27
unnamed: J3.28, J10.28, J17.28, J24.28, J31.28, J38.28, J45.28, J52.28, J59.28, J66.28
unnamed: J3.29, J10.29, J17.29, J24.29, J31.29, J38.29, J45.29, J52.29, J59.29, J66.29
unnamed: J3.30, J10.30, J17.30, J24.30, J31.30, J38.30, J45.30, J52.30, J59.30, J66.30
unnamed: J3.31, J10.31, J17.31, J24.31, J31.31, J38.31, J45.31, J52.31, J59.31, J66.31
unnamed: J3.32, J10.32, J17.32, J24.32, J31.32, J38.32, J45.32, J52.32, J59.32, J66.32
unnamed: J5.2, J12.2, J19.2, J26.2, J33.2, J40.2, J47.2, J54.2, J61.2, J68.2
unnamed: J5.3, J12.3, J19.3, J26.3, J33.3, J40.3, J47.3, J54.3, J61.3, J68.3
unnamed: J5.4, J12.4, J19.4, J26.4, J33.4, J40.4, J47.4, J54.4, J61.4, J68.4
unnamed: J5.5, J12.5, J19.5, J26.5, J33.5, J40.5, J47.5, J54.5, J61.5, J68.5
unnamed: J5.6, J12.6, J19.6, J26.6, J33.6, J40.6, J47.6, J54.6, J61.6, J68.6
unnamed: J5.7, J12.7, J19.7, J26.7, J33.7, J40.7, J47.7, J54.7, J61.7, J68.7
unnamed: J5.8, J12.8, J19.8, J26.8, J33.8, J40.8, J47.8, J54.8, J61.8, J68.8
unnamed: J5.9, J12.9, J19.9, J26.9, J33.9, J40.9, J47.9, J54.9, J61.9, J68.9
unnamed: J5.10, J12.10, J19.10, J26.10, J33.10, J40.10, J47.10, J54.10, J61.10, J68.10
unnamed: J5.11, J12.11, J19.11, J26.11, J33.11, J40.11, J47.11, J54.11, J61.11, J68.11
unnamed: J5.12, J12.12, J19.12, J26.12, J33.12, J40.12, J47.12, J54.12, J61.12, J68.12
unnamed: J5.13, J12.13, J19.13, J26.13, J33.13, J40.13, J47.13, J54.13, J61.13, J68.13
unnamed: J5.14, J12.14, J19.14, J26.14, J33.14, J40.14, J47.14, J54.14, J61.14, J68.14
unnamed: J5.15, J12.15, J19.15, J26.15, J33.15, J40.15, J47.15, J54.15, J61.15, J68.15
unnamed: J5.16, J12.16, J19.16, J26.16, J33.16, J40.16, J47.16, J54.16, J61.16, J68.16
unnamed: J5.17, J12.17, J19.17, J26.17, J33.17, J40.17, J47.17, J54.17, J61.17, J68.17
unnamed: J5.18, J12.18, J19.18, J26.18, J33.18, J40.18, J47.18, J54.18, J61.18, J68.18
unnamed: J5.19, J12.19, J19.19, J26.19, J33.19, J40.19, J47.19, J54.19, J61.19, J68.19
unnamed: J5.20, J12.20, J19.20, J26.20, J33.20, J40.20, J47.20, J54.20, J61.20, J68.20
unnamed: J5.21, J12.21, J19.21, J26.21, J33.21, J40.21, J47.21, J54.21, J61.21, J68.21
unnamed: J5.22, J12.22, J19.22, J26.22, J33.22, J40.22, J47.22, J54.22, J61.22, J68.22
unnamed: J5.23, J12.23, J19.23, J26.23, J33.23, J40.23, J47.23, J54.23, J61.23, J68.23
unnamed: J5.24, J12.24, J19.24, J26.24, J33.24, J40.24, J47.24, J54.24, J61.24, J68.24
unnamed: J5.25, J12.25, J19.25, J26.25, J33.25, J40.25, J47.25, J54.25, J61.25, J68.25
unnamed: J5.26, J12.26, J19.26, J26.26, J33.26, J40.26, J47.26, J54.26, J61.26, J68.26
unnamed: J5.27, J12.27, J19.27, J26.27, J33.27, J40.27, J47.27, J54.27, J61.27, J68.27
unnamed: J5.28, J12.28, J19.28, J26.28, J33.28, J40.28, J47.28, J54.28, J61.28, J68.28
unnamed: J5.29, J12.29, J19.29, J26.29, J33.29, J40.29, J47.29, J54.29, J61.29, J68.29
unnamed: J5.30, J12.30, J19.30, J26.30, J33.30, J40.30, J47.30, J54.30, J61.30, J68.30
unnamed: J5.31, J12.31, J19.31, J26.31, J33.31, J40.31, J47.31, J54.31, J61.31, J68.31
unnamed: J5.32, J12.32, J19.32, J26.32, J33.32, J40.32, J47.32, J54.32, J61.32, J68.32
unnamed: J7.2, J14.2, J21.2, J28.2, J35.2, J42.2, J49.2, J56.2, J63.2, J70.2
unnamed: J7.3, J14.3, J21.3, J28.3, J35.3, J42.3, J49.3, J56.3, J63.3, J70.3
unnamed: J7.6, J14.6, J21.6, J28.6, J35.6, J42.6, J49.6, J56.6, J63.6, J70.6
unnamed: J7.7, J14.7, J21.7, J28.7, J35.7, J42.7, J49.7, J56.7, J63.7, J70.7
unnamed: J7.8, J14.8, J21.8, J28.8, J35.8, J42.8, J49.8, J56.8, J63.8, J70.8
unnamed: J7.9, J14.9, J21.9, J28.9, J35.9, J42.9, J49.9, J56.9, J63.9, J70.9
unnamed: J7.10, J14.10, J21.10, J28.10, J35.10, J42.10, J49.10, J56.10, J63.10, J70.10
unnamed: J7.11, J14.11, J21.11, J28.11, J35.11, J42.11, J49.11, J56.11, J63.11, J70.11
unnamed: J7.12, J14.12, J21.12, J28.12, J35.12, J42.12, J49.12, J56.12, J63.12, J70.12
unnamed: J7.13, J14.13, J21.13, J28.13, J35.13, J42.13, J49.13, J56.13, J63.13, J70.13
unnamed: J7.14, J14.14, J21.14, J28.14, J35.14, J42.14, J49.14, J56.14, J63.14, J70.14
unnamed: J7.15, J14.15, J21.15, J28.15, J35.15, J42.15, J49.15, J56.15, J63.15, J70.15
unnamed: J7.16, J14.16, J21.16, J28.16, J35.16, J42.16, J49.16, J56.16, J63.16, J70.16
unnamed: J7.17, J14.17, J21.17, J28.17, J35.17, J42.17, J49.17, J56.17, J63.17, J70.17
unnamed: J7.18, J14.18, J21.18, J28.18, J35.18, J42.18, J49.18, J56.18, J63.18, J70.18
unnamed: J7.19, J14.19, J21.19, J28.19, J35.19, J42.19, J49.19, J56.19, J63.19, J70.19
unnamed: J7.20, J14.20, J21.20, J28.20, J35.20, J42.20, J49.20, J56.20, J63.20, J70.20
unnamed: J7.21, J14.21, J21.21, J28.21, J35.21, J42.21, J49.21, J56.21, J63.21, J70.21
unnamed: J7.22, J14.22, J21.22, J28.22, J35.22, J42.22, J49.22, J56.22, J63.22, J70.22
unnamed: J7.23, J14.23, J21.23, J28.23, J35.23, J42.23, J49.23, J56.23, J63.23, J70.23
unnamed: J7.24, J14.24, J21.24, J28.24, J35.24, J42.24, J49.24, J56.24, J63.24, J70.24
unnamed: J7.25, J14.25, J21.25, J28.25, J35.25, J42.25, J49.25, J56.25, J63.25, J70.25
unnamed: J7.26, J14.26, J21.26, J28.26, J35.26, J42.26, J49.26, J56.26, J63.26, J70.26
unnamed: J7.27, J14.27, J21.27, J28.27, J35.27, J42.27, J49.27, J56.27, J63.27, J70.27
unnamed: J7.28, J14.28, J21.28, J28.28, J35.28, J42.28, J49.28, J56.28, J63.28, J70.28
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

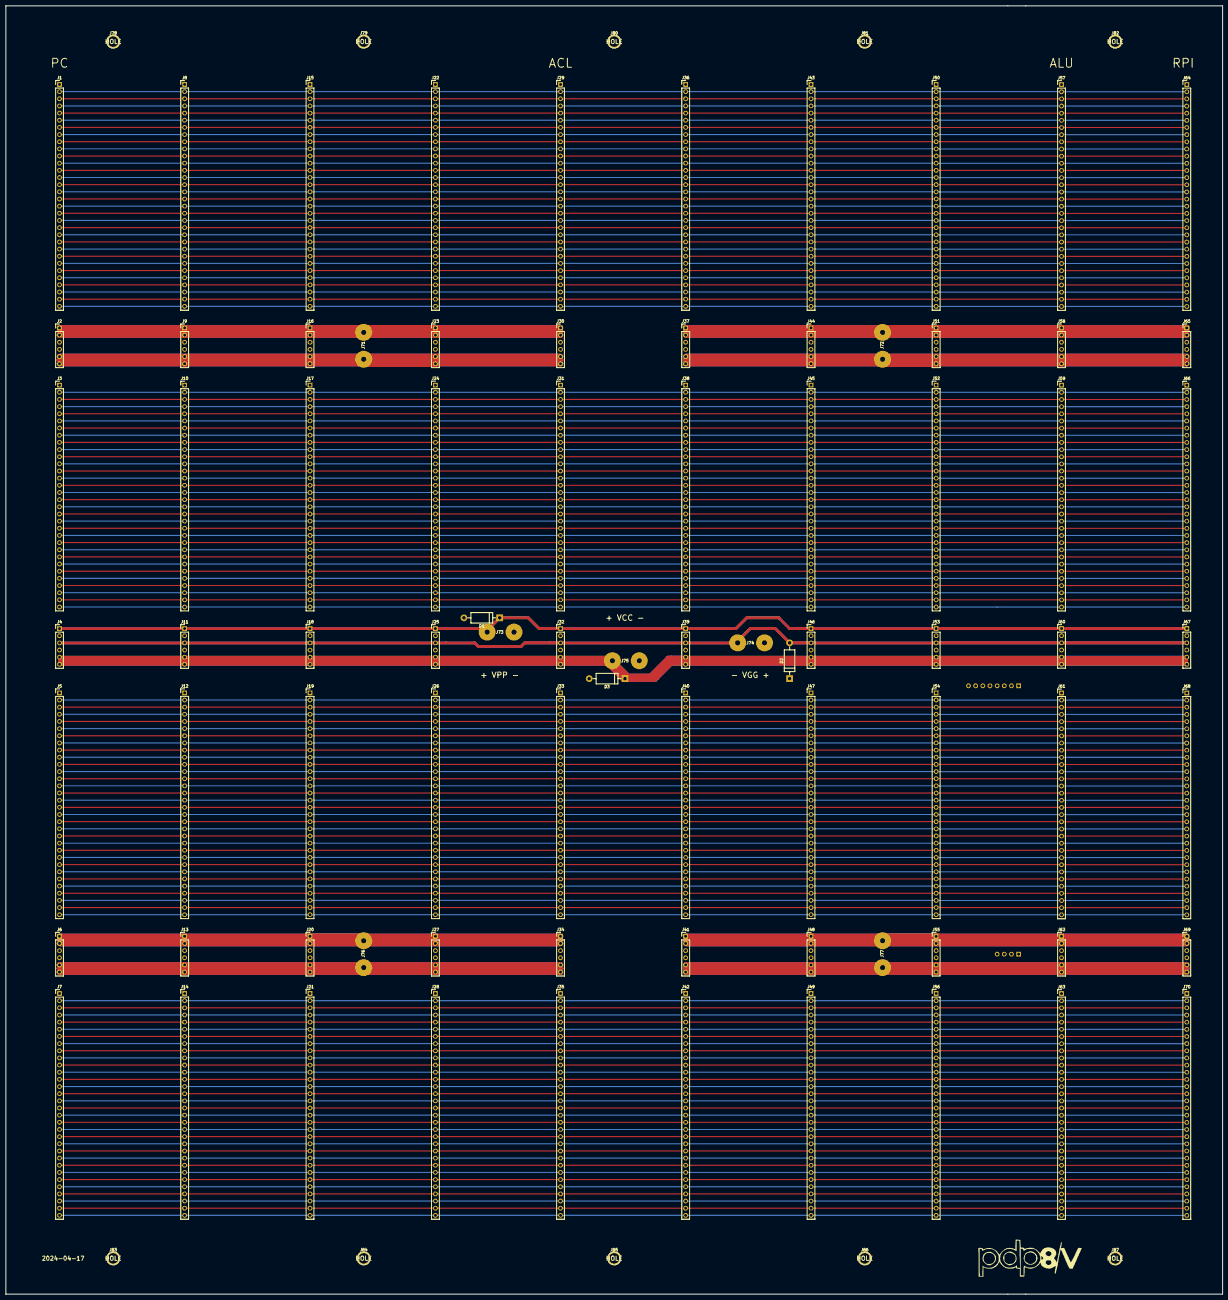
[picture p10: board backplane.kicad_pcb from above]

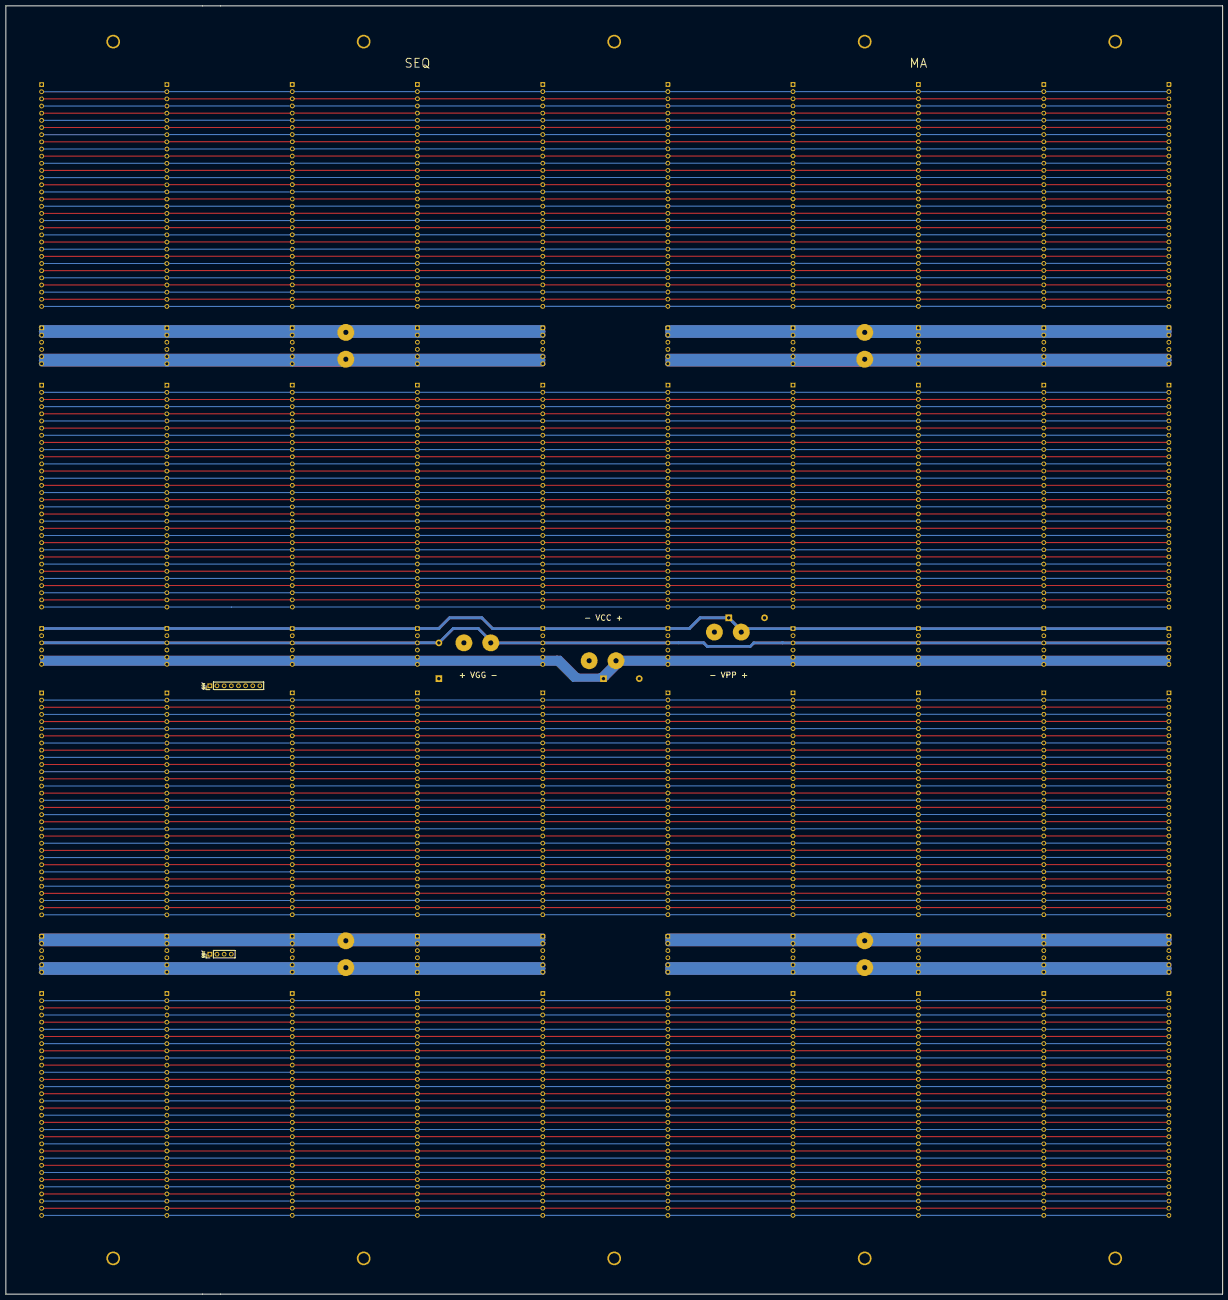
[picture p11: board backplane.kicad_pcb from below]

Board: 4 copper layers, 431.8 x 457.2 mm, 92 parts (2 on the bottom side), 136 nets.

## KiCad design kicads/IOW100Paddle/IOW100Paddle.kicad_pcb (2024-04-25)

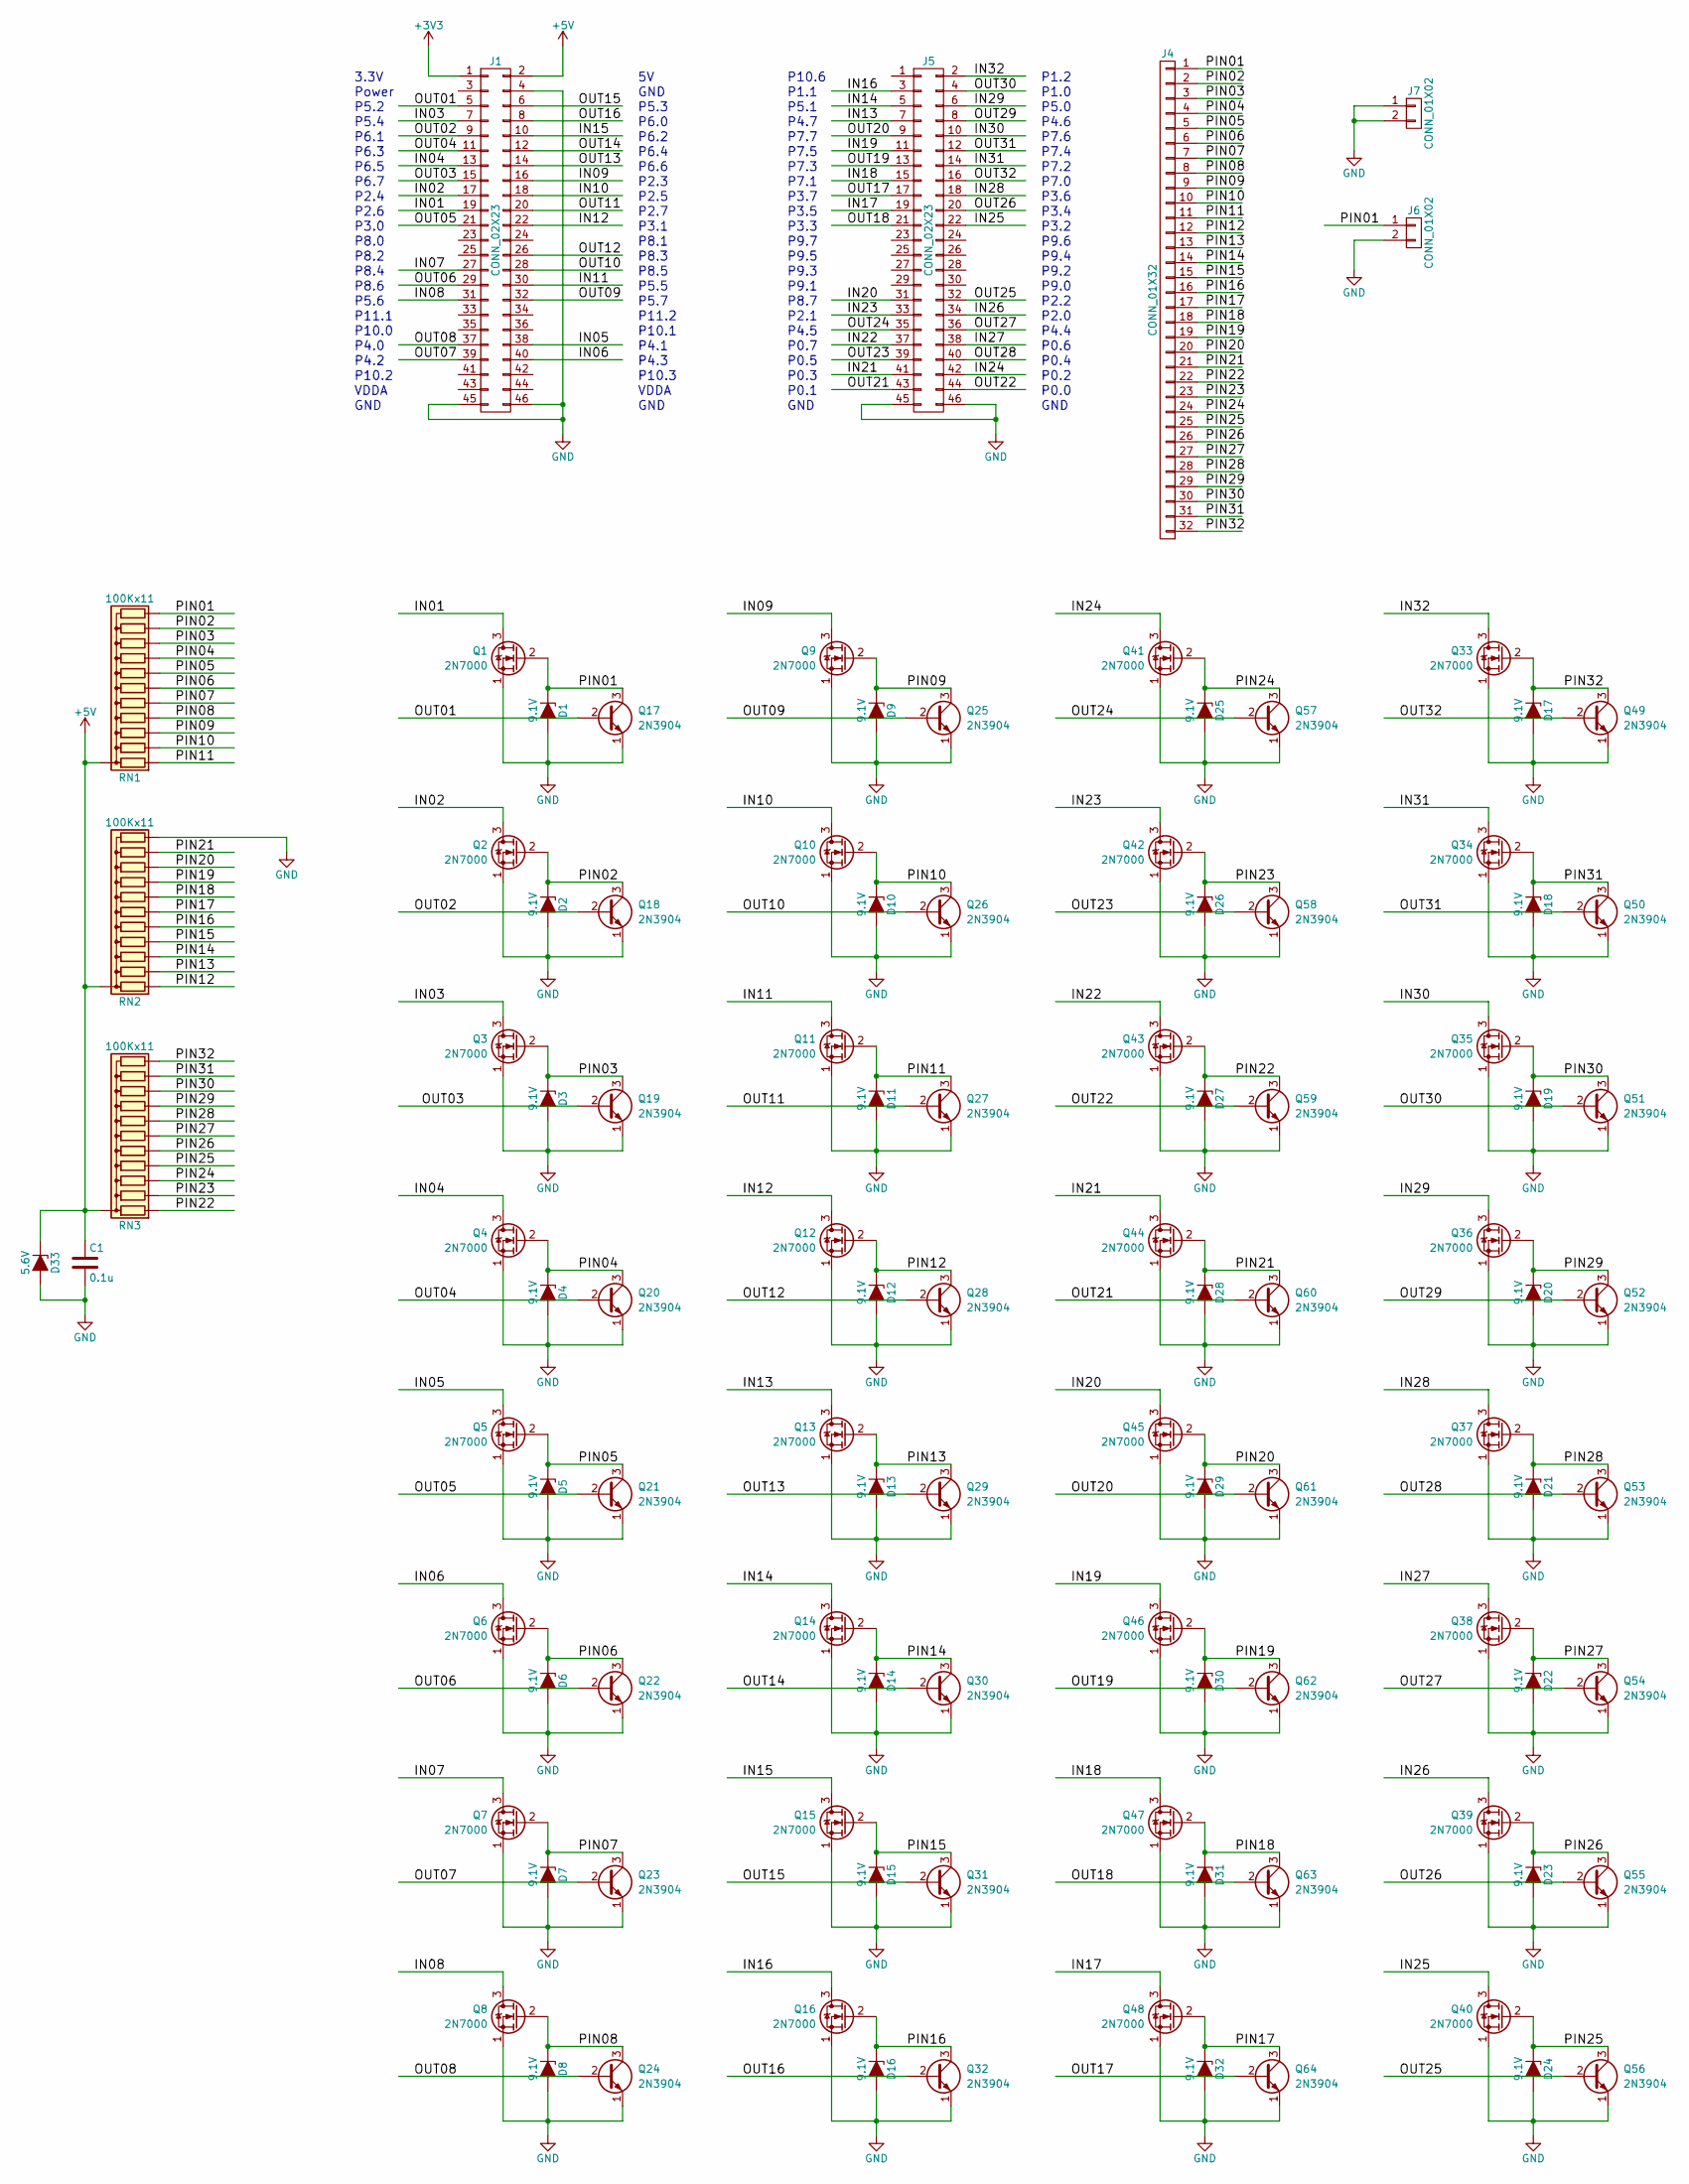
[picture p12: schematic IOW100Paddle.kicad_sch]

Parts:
C1: 0.1u; C_Axial_L3.8mm_D2.6mm_P7.50mm_Horizontal
D1, D2, D3, D4, D5, D6, D7, D8, D9, D10, D11, D12, D13, D14, D15, D16, D17, D18, D19, D20, D21, D22, D23, D24, D25, D26, D27, D28, D29, D30, D31, D32: 9.1V; D_DO-35_SOD27_P6.35mm_Horizontal
D33: 5.6V; D_DO-35_SOD27_P6.35mm_Horizontal
J1, J5: CONN_02X23; Pin_Header_Straight_2x23_Pitch2.54mm
J4: CONN_01X32; Pin_Header_Straight_1x32_Pitch2.54mm
J6, J7: CONN_01X02; Pin_Header_Straight_1x02_Pitch2.54mm
Q1, Q2, Q3, Q4, Q5, Q6, Q7, Q8, Q9, Q10, Q11, Q12, Q13, Q14, Q15, Q16, Q33, Q34, Q35, Q36, Q37, Q38, Q39, Q40, Q41, Q42, Q43, Q44, Q45, Q46, Q47, Q48: 2N7000; TO-92_Molded_Wide
Q17, Q18, Q19, Q20, Q21, Q22, Q23, Q24, Q25, Q26, Q27, Q28, Q29, Q30, Q31, Q32, Q49, Q50, Q51, Q52, Q53, Q54, Q55, Q56, Q57, Q58, Q59, Q60, Q61, Q62, Q63, Q64: 2N3904; TO-92_Molded_Wide
RN1, RN2, RN3: 100Kx11; R_Array_SIP12

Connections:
+3V3: J1.1
+5V: C1.1, D33.1 (K), J1.2, RN1.1 (common), RN2.1 (common), RN3.1 (common)
/IN01: J1.19, Q1.3 (D)
/IN02: J1.17, Q2.3 (D)
/IN03: J1.7, Q3.3 (D)
/IN04: J1.13, Q4.3 (D)
/IN05: J1.38, Q5.3 (D)
/IN06: J1.40, Q6.3 (D)
/IN07: J1.27, Q7.3 (D)
/IN08: J1.31, Q8.3 (D)
/IN09: J1.16, Q9.3 (D)
/IN10: J1.18, Q10.3 (D)
/IN11: J1.30, Q11.3 (D)
/IN12: J1.22, Q12.3 (D)
/IN13: J5.7, Q13.3 (D)
/IN14: J5.5, Q14.3 (D)
/IN15: J1.10, Q15.3 (D)
/IN16: J5.3, Q16.3 (D)
/IN17: J5.19, Q48.3 (D)
/IN18: J5.15, Q47.3 (D)
/IN19: J5.11, Q46.3 (D)
/IN20: J5.31, Q45.3 (D)
/IN21: J5.41, Q44.3 (D)
/IN22: J5.37, Q43.3 (D)
/IN23: J5.33, Q42.3 (D)
/IN24: J5.42, Q41.3 (D)
/IN25: J5.22, Q40.3 (D)
/IN26: J5.34, Q39.3 (D)
/IN27: J5.38, Q38.3 (D)
/IN28: J5.18, Q37.3 (D)
/IN29: J5.6, Q36.3 (D)
/IN30: J5.10, Q35.3 (D)
/IN31: J5.14, Q34.3 (D)
/IN32: J5.2, Q33.3 (D)
/OUT01: J1.5, Q17.2 (B)
/OUT02: J1.9, Q18.2 (B)
/OUT03: J1.15, Q19.2 (B)
/OUT04: J1.11, Q20.2 (B)
/OUT05: J1.21, Q21.2 (B)
/OUT06: J1.29, Q22.2 (B)
/OUT07: J1.39, Q23.2 (B)
/OUT08: J1.37, Q24.2 (B)
/OUT09: J1.32, Q25.2 (B)
/OUT10: J1.28, Q26.2 (B)
/OUT11: J1.20, Q27.2 (B)
/OUT12: J1.26, Q28.2 (B)
/OUT13: J1.14, Q29.2 (B)
/OUT14: J1.12, Q30.2 (B)
/OUT15: J1.6, Q31.2 (B)
/OUT16: J1.8, Q32.2 (B)
/OUT17: J5.17, Q64.2 (B)
/OUT18: J5.21, Q63.2 (B)
/OUT19: J5.13, Q62.2 (B)
/OUT20: J5.9, Q61.2 (B)
/OUT21: J5.43, Q60.2 (B)
/OUT22: J5.44, Q59.2 (B)
/OUT23: J5.39, Q58.2 (B)
/OUT24: J5.35, Q57.2 (B)
/OUT25: J5.32, Q56.2 (B)
/OUT26: J5.20, Q55.2 (B)
/OUT27: J5.36, Q54.2 (B)
/OUT28: J5.40, Q53.2 (B)
/OUT29: J5.8, Q52.2 (B)
/OUT30: J5.4, Q51.2 (B)
/OUT31: J5.12, Q50.2 (B)
/OUT32: J5.16, Q49.2 (B)
/PIN01: D1.1 (K), J4.1, J6.1, Q1.2 (G), Q17.3 (C), RN1.12 (R11)
/PIN02: D2.1 (K), J4.2, Q2.2 (G), Q18.3 (C), RN1.11 (R10)
/PIN03: D3.1 (K), J4.3, Q3.2 (G), Q19.3 (C), RN1.10 (R9)
/PIN04: D4.1 (K), J4.4, Q4.2 (G), Q20.3 (C), RN1.9 (R8)
/PIN05: D5.1 (K), J4.5, Q5.2 (G), Q21.3 (C), RN1.8 (R7)
/PIN06: D6.1 (K), J4.6, Q6.2 (G), Q22.3 (C), RN1.7 (R6)
/PIN07: D7.1 (K), J4.7, Q7.2 (G), Q23.3 (C), RN1.6 (R5)
/PIN08: D8.1 (K), J4.8, Q8.2 (G), Q24.3 (C), RN1.5 (R4)
/PIN09: D9.1 (K), J4.9, Q9.2 (G), Q25.3 (C), RN1.4 (R3)
/PIN10: D10.1 (K), J4.10, Q10.2 (G), Q26.3 (C), RN1.3 (R2)
/PIN11: D11.1 (K), J4.11, Q11.2 (G), Q27.3 (C), RN1.2 (R1)
/PIN12: D12.1 (K), J4.12, Q12.2 (G), Q28.3 (C), RN2.2 (R1)
/PIN13: D13.1 (K), J4.13, Q13.2 (G), Q29.3 (C), RN2.3 (R2)
/PIN14: D14.1 (K), J4.14, Q14.2 (G), Q30.3 (C), RN2.4 (R3)
/PIN15: D15.1 (K), J4.15, Q15.2 (G), Q31.3 (C), RN2.5 (R4)
/PIN16: D16.1 (K), J4.16, Q16.2 (G), Q32.3 (C), RN2.6 (R5)
/PIN17: D32.1 (K), J4.17, Q48.2 (G), Q64.3 (C), RN2.7 (R6)
/PIN18: D31.1 (K), J4.18, Q47.2 (G), Q63.3 (C), RN2.8 (R7)
/PIN19: D30.1 (K), J4.19, Q46.2 (G), Q62.3 (C), RN2.9 (R8)
/PIN20: D29.1 (K), J4.20, Q45.2 (G), Q61.3 (C), RN2.10 (R9)
/PIN21: D28.1 (K), J4.21, Q44.2 (G), Q60.3 (C), RN2.11 (R10)
/PIN22: D27.1 (K), J4.22, Q43.2 (G), Q59.3 (C), RN3.2 (R1)
/PIN23: D26.1 (K), J4.23, Q42.2 (G), Q58.3 (C), RN3.3 (R2)
/PIN24: D25.1 (K), J4.24, Q41.2 (G), Q57.3 (C), RN3.4 (R3)
/PIN25: D24.1 (K), J4.25, Q40.2 (G), Q56.3 (C), RN3.5 (R4)
/PIN26: D23.1 (K), J4.26, Q39.2 (G), Q55.3 (C), RN3.6 (R5)
/PIN27: D22.1 (K), J4.27, Q38.2 (G), Q54.3 (C), RN3.7 (R6)
/PIN28: D21.1 (K), J4.28, Q37.2 (G), Q53.3 (C), RN3.8 (R7)
/PIN29: D20.1 (K), J4.29, Q36.2 (G), Q52.3 (C), RN3.9 (R8)
/PIN30: D19.1 (K), J4.30, Q35.2 (G), Q51.3 (C), RN3.10 (R9)
/PIN31: D18.1 (K), J4.31, Q34.2 (G), Q50.3 (C), RN3.11 (R10)
/PIN32: D17.1 (K), J4.32, Q33.2 (G), Q49.3 (C), RN3.12 (R11)
GND: C1.2, D1.2 (A), D2.2 (A), D3.2 (A), D4.2 (A), D5.2 (A), D6.2 (A), D7.2 (A), D8.2 (A), D9.2 (A), D10.2 (A), D11.2 (A), D12.2 (A), D13.2 (A), D14.2 (A), D15.2 (A), D16.2 (A), D17.2 (A), D18.2 (A), D19.2 (A), D20.2 (A), D21.2 (A), D22.2 (A), D23.2 (A), D24.2 (A), D25.2 (A), D26.2 (A), D27.2 (A), D28.2 (A), D29.2 (A), D30.2 (A), D31.2 (A), D32.2 (A), D33.2 (A), J1.4, J1.45, J1.46, J5.45, J5.46, J6.2, J7.1, J7.2, Q1.1 (S), Q2.1 (S), Q3.1 (S), Q4.1 (S), Q5.1 (S), Q6.1 (S), Q7.1 (S), Q8.1 (S), Q9.1 (S), Q10.1 (S), Q11.1 (S), Q12.1 (S), Q13.1 (S), Q14.1 (S), Q15.1 (S), Q16.1 (S), Q17.1 (E), Q18.1 (E), Q19.1 (E), Q20.1 (E), Q21.1 (E), Q22.1 (E), Q23.1 (E), Q24.1 (E), Q25.1 (E), Q26.1 (E), Q27.1 (E), Q28.1 (E), Q29.1 (E), Q30.1 (E), Q31.1 (E), Q32.1 (E), Q33.1 (S), Q34.1 (S), Q35.1 (S), Q36.1 (S), Q37.1 (S), Q38.1 (S), Q39.1 (S), Q40.1 (S), Q41.1 (S), Q42.1 (S), Q43.1 (S), Q44.1 (S), Q45.1 (S), Q46.1 (S), Q47.1 (S), Q48.1 (S), Q49.1 (E), Q50.1 (E), Q51.1 (E), Q52.1 (E), Q53.1 (E), Q54.1 (E), Q55.1 (E), Q56.1 (E), Q57.1 (E), Q58.1 (E), Q59.1 (E), Q60.1 (E), Q61.1 (E), Q62.1 (E), Q63.1 (E), Q64.1 (E), RN2.12 (R11)

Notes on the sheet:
VDDA
P6.0
P3.3
P10.6
P8.0
P4.3
P2.1
P5.5
P7.4
P0.4
P6.4
P1.1
P9.5
P5.7
P2.3
P5.6
P4.6
P3.1
P0.7
P5.1
GND
P6.7
P8.7
P3.7
P6.6
P6.2
P0.5
Power
P7.5
P7.2
3.3V
P8.6
P3.2
P2.2
P11.2
P0.1
P2.0
P8.1
P4.7
P5.2

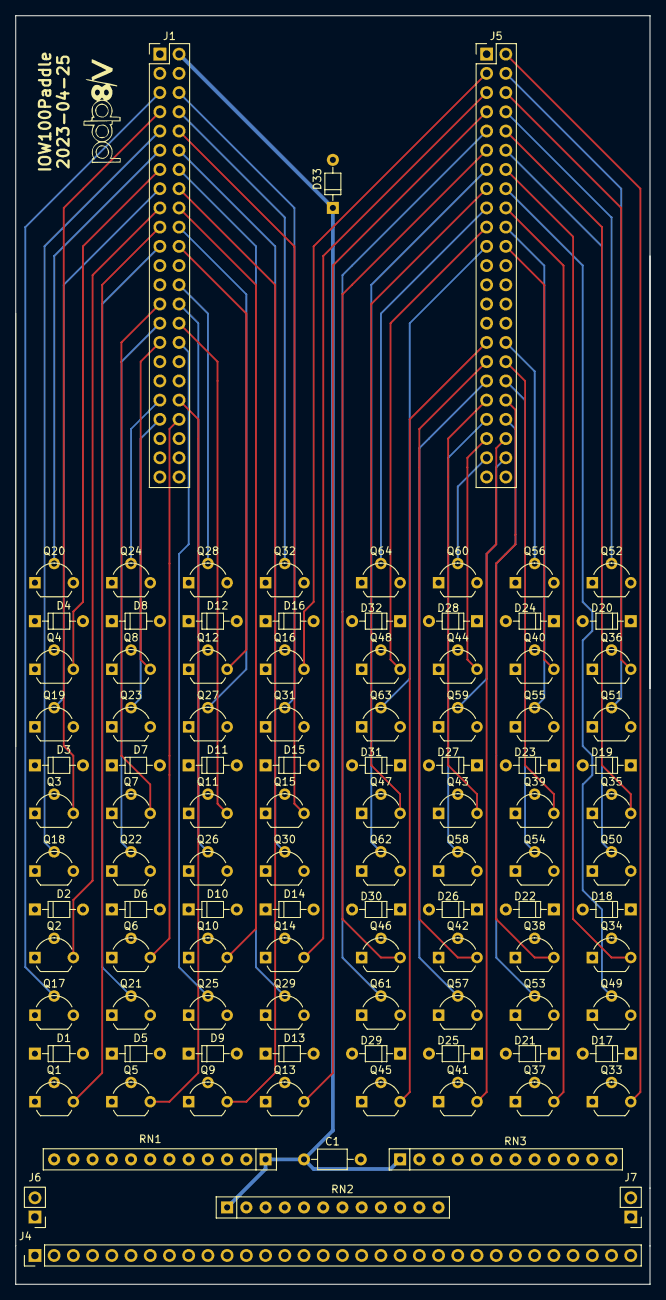
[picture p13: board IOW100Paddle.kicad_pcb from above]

Board: 4 copper layers, 83.8 x 167.6 mm, 106 parts (0 on the bottom side), 98 nets.

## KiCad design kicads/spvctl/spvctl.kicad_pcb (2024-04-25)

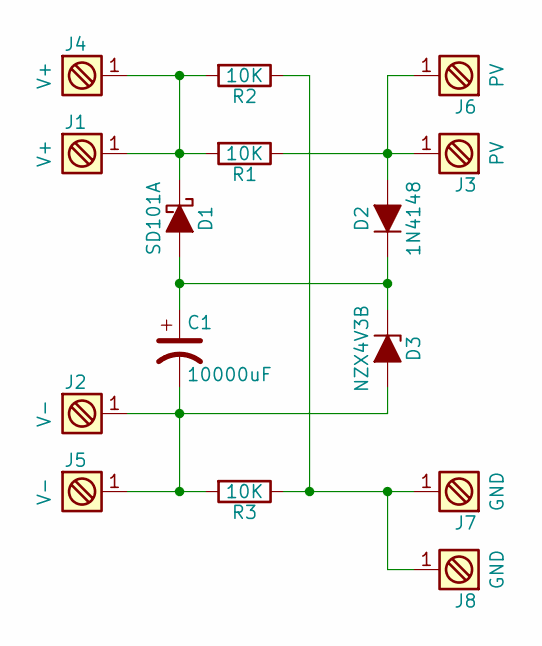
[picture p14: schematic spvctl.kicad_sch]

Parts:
C1: 10000uF; CP_Radial_D16.0mm_P7.50mm
D1: SD101A; D_DO-35_SOD27_P7.62mm_Horizontal
D2: 1N4148; D_DO-35_SOD27_P7.62mm_Horizontal
D3: NZX4V3B; D_DO-35_SOD27_P7.62mm_Horizontal
J1, J4: V+; PINTST
J2, J5: V-; PINTST
J3, J6: PV; PINTST
J7, J8: GND; PINTST
R1, R2, R3: 10K; R_Axial_DIN0207_L6.3mm_D2.5mm_P7.62mm_Horizontal

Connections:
unnamed: C1.1, D1.2 (A), D2.1 (K), D3.1 (K)
unnamed: C1.2, D3.2 (A), J2.1, J5.1, R3.2
unnamed: D1.1 (K), J1.1, J4.1, R1.2, R2.2
unnamed: D2.2 (A), J3.1, J6.1, R1.1
unnamed: J7.1, J8.1, R2.1, R3.1

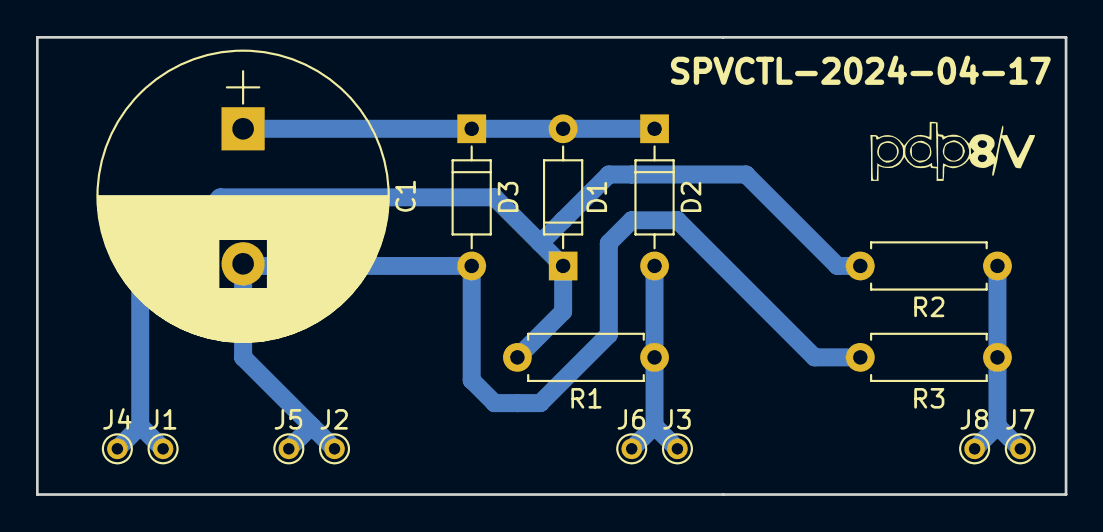
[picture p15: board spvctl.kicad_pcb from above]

Board: 2 copper layers, 57.1 x 25.4 mm, 15 parts (0 on the bottom side), 5 nets.

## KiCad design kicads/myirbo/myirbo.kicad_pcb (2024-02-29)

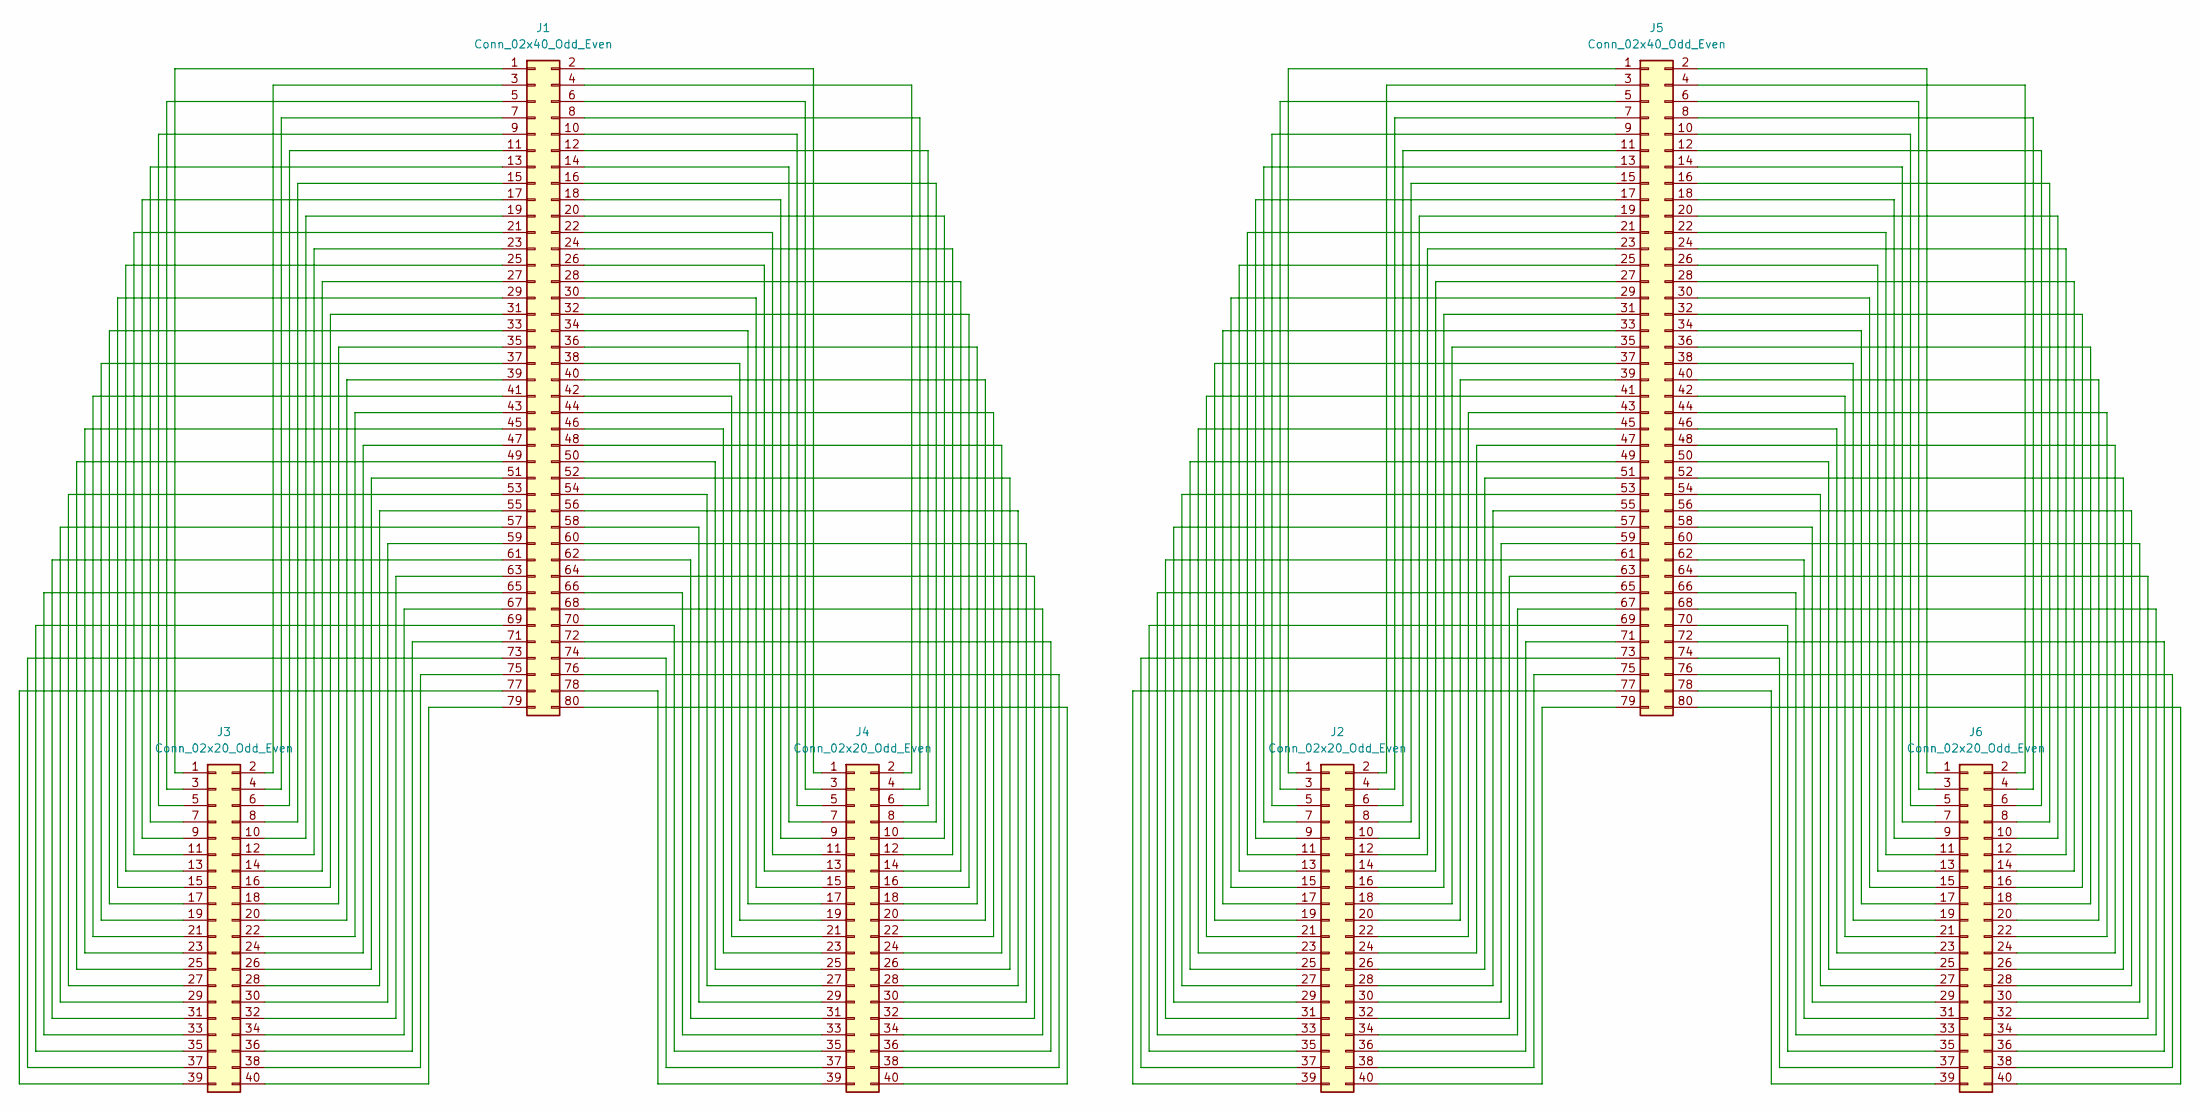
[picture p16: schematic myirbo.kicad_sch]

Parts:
J1, J5: Conn_02x40_Odd_Even; PinHeader_2x40_P1.27mm_Vertical
J2, J3, J4, J6: Conn_02x20_Odd_Even; PinHeader_2x20_P2.54mm_Vertical

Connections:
unnamed: J1.1, J3.1
unnamed: J1.2, J4.1
unnamed: J1.3, J3.2
unnamed: J1.4, J4.2
unnamed: J1.5, J3.3
unnamed: J1.6, J4.3
unnamed: J1.7, J3.4
unnamed: J1.8, J4.4
unnamed: J1.9, J3.5
unnamed: J1.10, J4.5
unnamed: J1.11, J3.6
unnamed: J1.12, J4.6
unnamed: J1.13, J3.7
unnamed: J1.14, J4.7
unnamed: J1.15, J3.8
unnamed: J1.16, J4.8
unnamed: J1.17, J3.9
unnamed: J1.18, J4.9
unnamed: J1.19, J3.10
unnamed: J1.20, J4.10
unnamed: J1.21, J3.11
unnamed: J1.22, J4.11
unnamed: J1.23, J3.12
unnamed: J1.24, J4.12
unnamed: J1.25, J3.13
unnamed: J1.26, J4.13
unnamed: J1.27, J3.14
unnamed: J1.28, J4.14
unnamed: J1.29, J3.15
unnamed: J1.30, J4.15
unnamed: J1.31, J3.16
unnamed: J1.32, J4.16
unnamed: J1.33, J3.17
unnamed: J1.34, J4.17
unnamed: J1.35, J3.18
unnamed: J1.36, J4.18
unnamed: J1.37, J3.19
unnamed: J1.38, J4.19
unnamed: J1.39, J3.20
unnamed: J1.40, J4.20
unnamed: J1.41, J3.21
unnamed: J1.42, J4.21
unnamed: J1.43, J3.22
unnamed: J1.44, J4.22
unnamed: J1.45, J3.23
unnamed: J1.46, J4.23
unnamed: J1.47, J3.24
unnamed: J1.48, J4.24
unnamed: J1.49, J3.25
unnamed: J1.50, J4.25
unnamed: J1.51, J3.26
unnamed: J1.52, J4.26
unnamed: J1.53, J3.27
unnamed: J1.54, J4.27
unnamed: J1.55, J3.28
unnamed: J1.56, J4.28
unnamed: J1.57, J3.29
unnamed: J1.58, J4.29
unnamed: J1.59, J3.30
unnamed: J1.60, J4.30
unnamed: J1.61, J3.31
unnamed: J1.62, J4.31
unnamed: J1.63, J3.32
unnamed: J1.64, J4.32
unnamed: J1.65, J3.33
unnamed: J1.66, J4.33
unnamed: J1.67, J3.34
unnamed: J1.68, J4.34
unnamed: J1.69, J3.35
unnamed: J1.70, J4.35
unnamed: J1.71, J3.36
unnamed: J1.72, J4.36
unnamed: J1.73, J3.37
unnamed: J1.74, J4.37
unnamed: J1.75, J3.38
unnamed: J1.76, J4.38
unnamed: J1.77, J3.39
unnamed: J1.78, J4.39
unnamed: J1.79, J3.40
unnamed: J1.80, J4.40
unnamed: J2.1, J5.1
unnamed: J2.2, J5.3
unnamed: J2.3, J5.5
unnamed: J2.4, J5.7
unnamed: J2.5, J5.9
unnamed: J2.6, J5.11
unnamed: J2.7, J5.13
unnamed: J2.8, J5.15
unnamed: J2.9, J5.17
unnamed: J2.10, J5.19
unnamed: J2.11, J5.21
unnamed: J2.12, J5.23
unnamed: J2.13, J5.25
unnamed: J2.14, J5.27
unnamed: J2.15, J5.29
unnamed: J2.16, J5.31
unnamed: J2.17, J5.33
unnamed: J2.18, J5.35
unnamed: J2.19, J5.37
unnamed: J2.20, J5.39
unnamed: J2.21, J5.41
unnamed: J2.22, J5.43
unnamed: J2.23, J5.45
unnamed: J2.24, J5.47
unnamed: J2.25, J5.49
unnamed: J2.26, J5.51
unnamed: J2.27, J5.53
unnamed: J2.28, J5.55
unnamed: J2.29, J5.57
unnamed: J2.30, J5.59
unnamed: J2.31, J5.61
unnamed: J2.32, J5.63
unnamed: J2.33, J5.65
unnamed: J2.34, J5.67
unnamed: J2.35, J5.69
unnamed: J2.36, J5.71
unnamed: J2.37, J5.73
unnamed: J2.38, J5.75
unnamed: J2.39, J5.77
unnamed: J2.40, J5.79
unnamed: J5.2, J6.1
unnamed: J5.4, J6.2
unnamed: J5.6, J6.3
unnamed: J5.8, J6.4
unnamed: J5.10, J6.5
unnamed: J5.12, J6.6
unnamed: J5.14, J6.7
unnamed: J5.16, J6.8
unnamed: J5.18, J6.9
unnamed: J5.20, J6.10
unnamed: J5.22, J6.11
unnamed: J5.24, J6.12
unnamed: J5.26, J6.13
unnamed: J5.28, J6.14
unnamed: J5.30, J6.15
unnamed: J5.32, J6.16
unnamed: J5.34, J6.17
unnamed: J5.36, J6.18
unnamed: J5.38, J6.19
unnamed: J5.40, J6.20
unnamed: J5.42, J6.21
unnamed: J5.44, J6.22
unnamed: J5.46, J6.23
unnamed: J5.48, J6.24
unnamed: J5.50, J6.25
unnamed: J5.52, J6.26
unnamed: J5.54, J6.27
unnamed: J5.56, J6.28
unnamed: J5.58, J6.29
unnamed: J5.60, J6.30
unnamed: J5.62, J6.31
unnamed: J5.64, J6.32
unnamed: J5.66, J6.33
unnamed: J5.68, J6.34
unnamed: J5.70, J6.35
unnamed: J5.72, J6.36
unnamed: J5.74, J6.37
unnamed: J5.76, J6.38
unnamed: J5.78, J6.39
unnamed: J5.80, J6.40

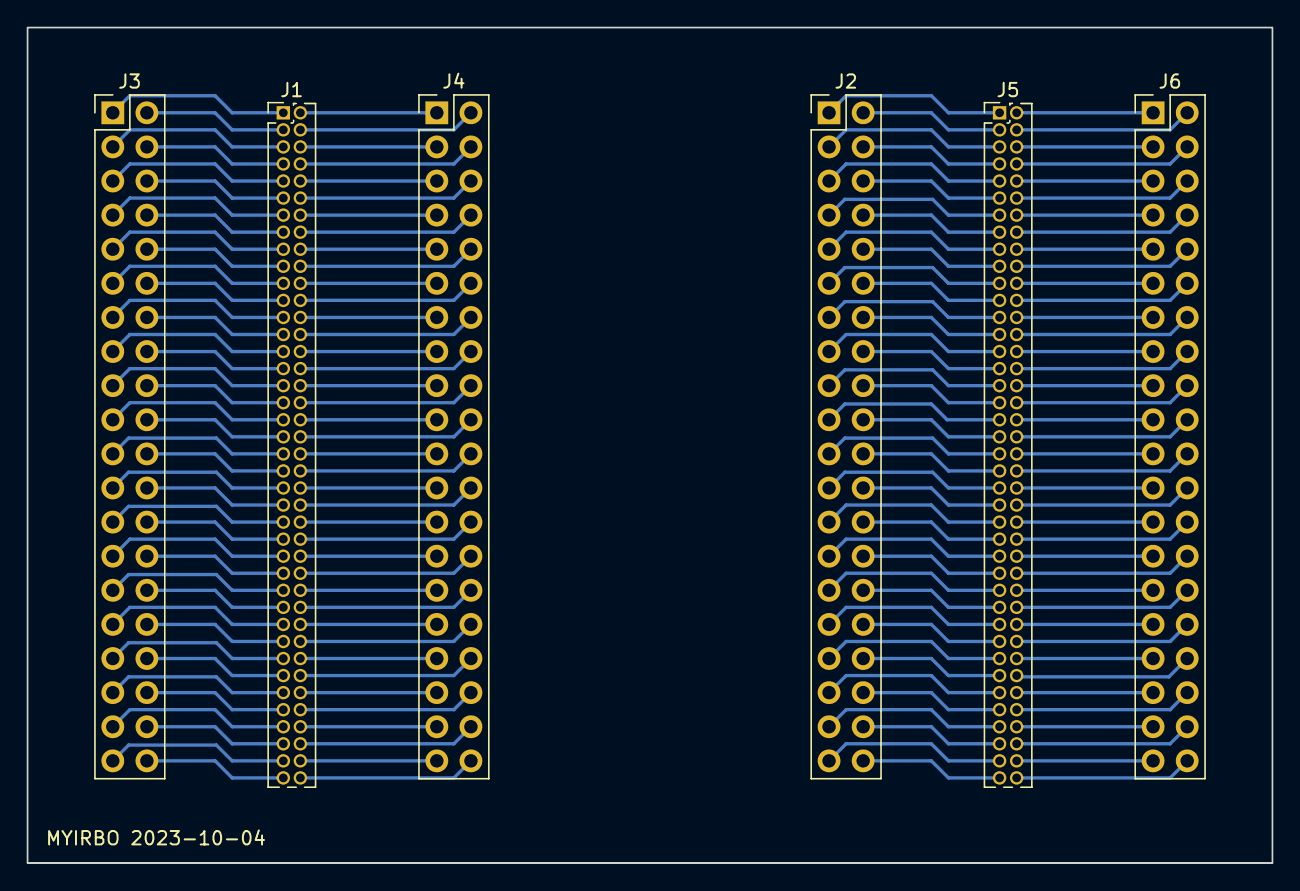
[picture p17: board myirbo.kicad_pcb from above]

Board: 2 copper layers, 92.7 x 62.2 mm, 6 parts (0 on the bottom side), 160 nets.

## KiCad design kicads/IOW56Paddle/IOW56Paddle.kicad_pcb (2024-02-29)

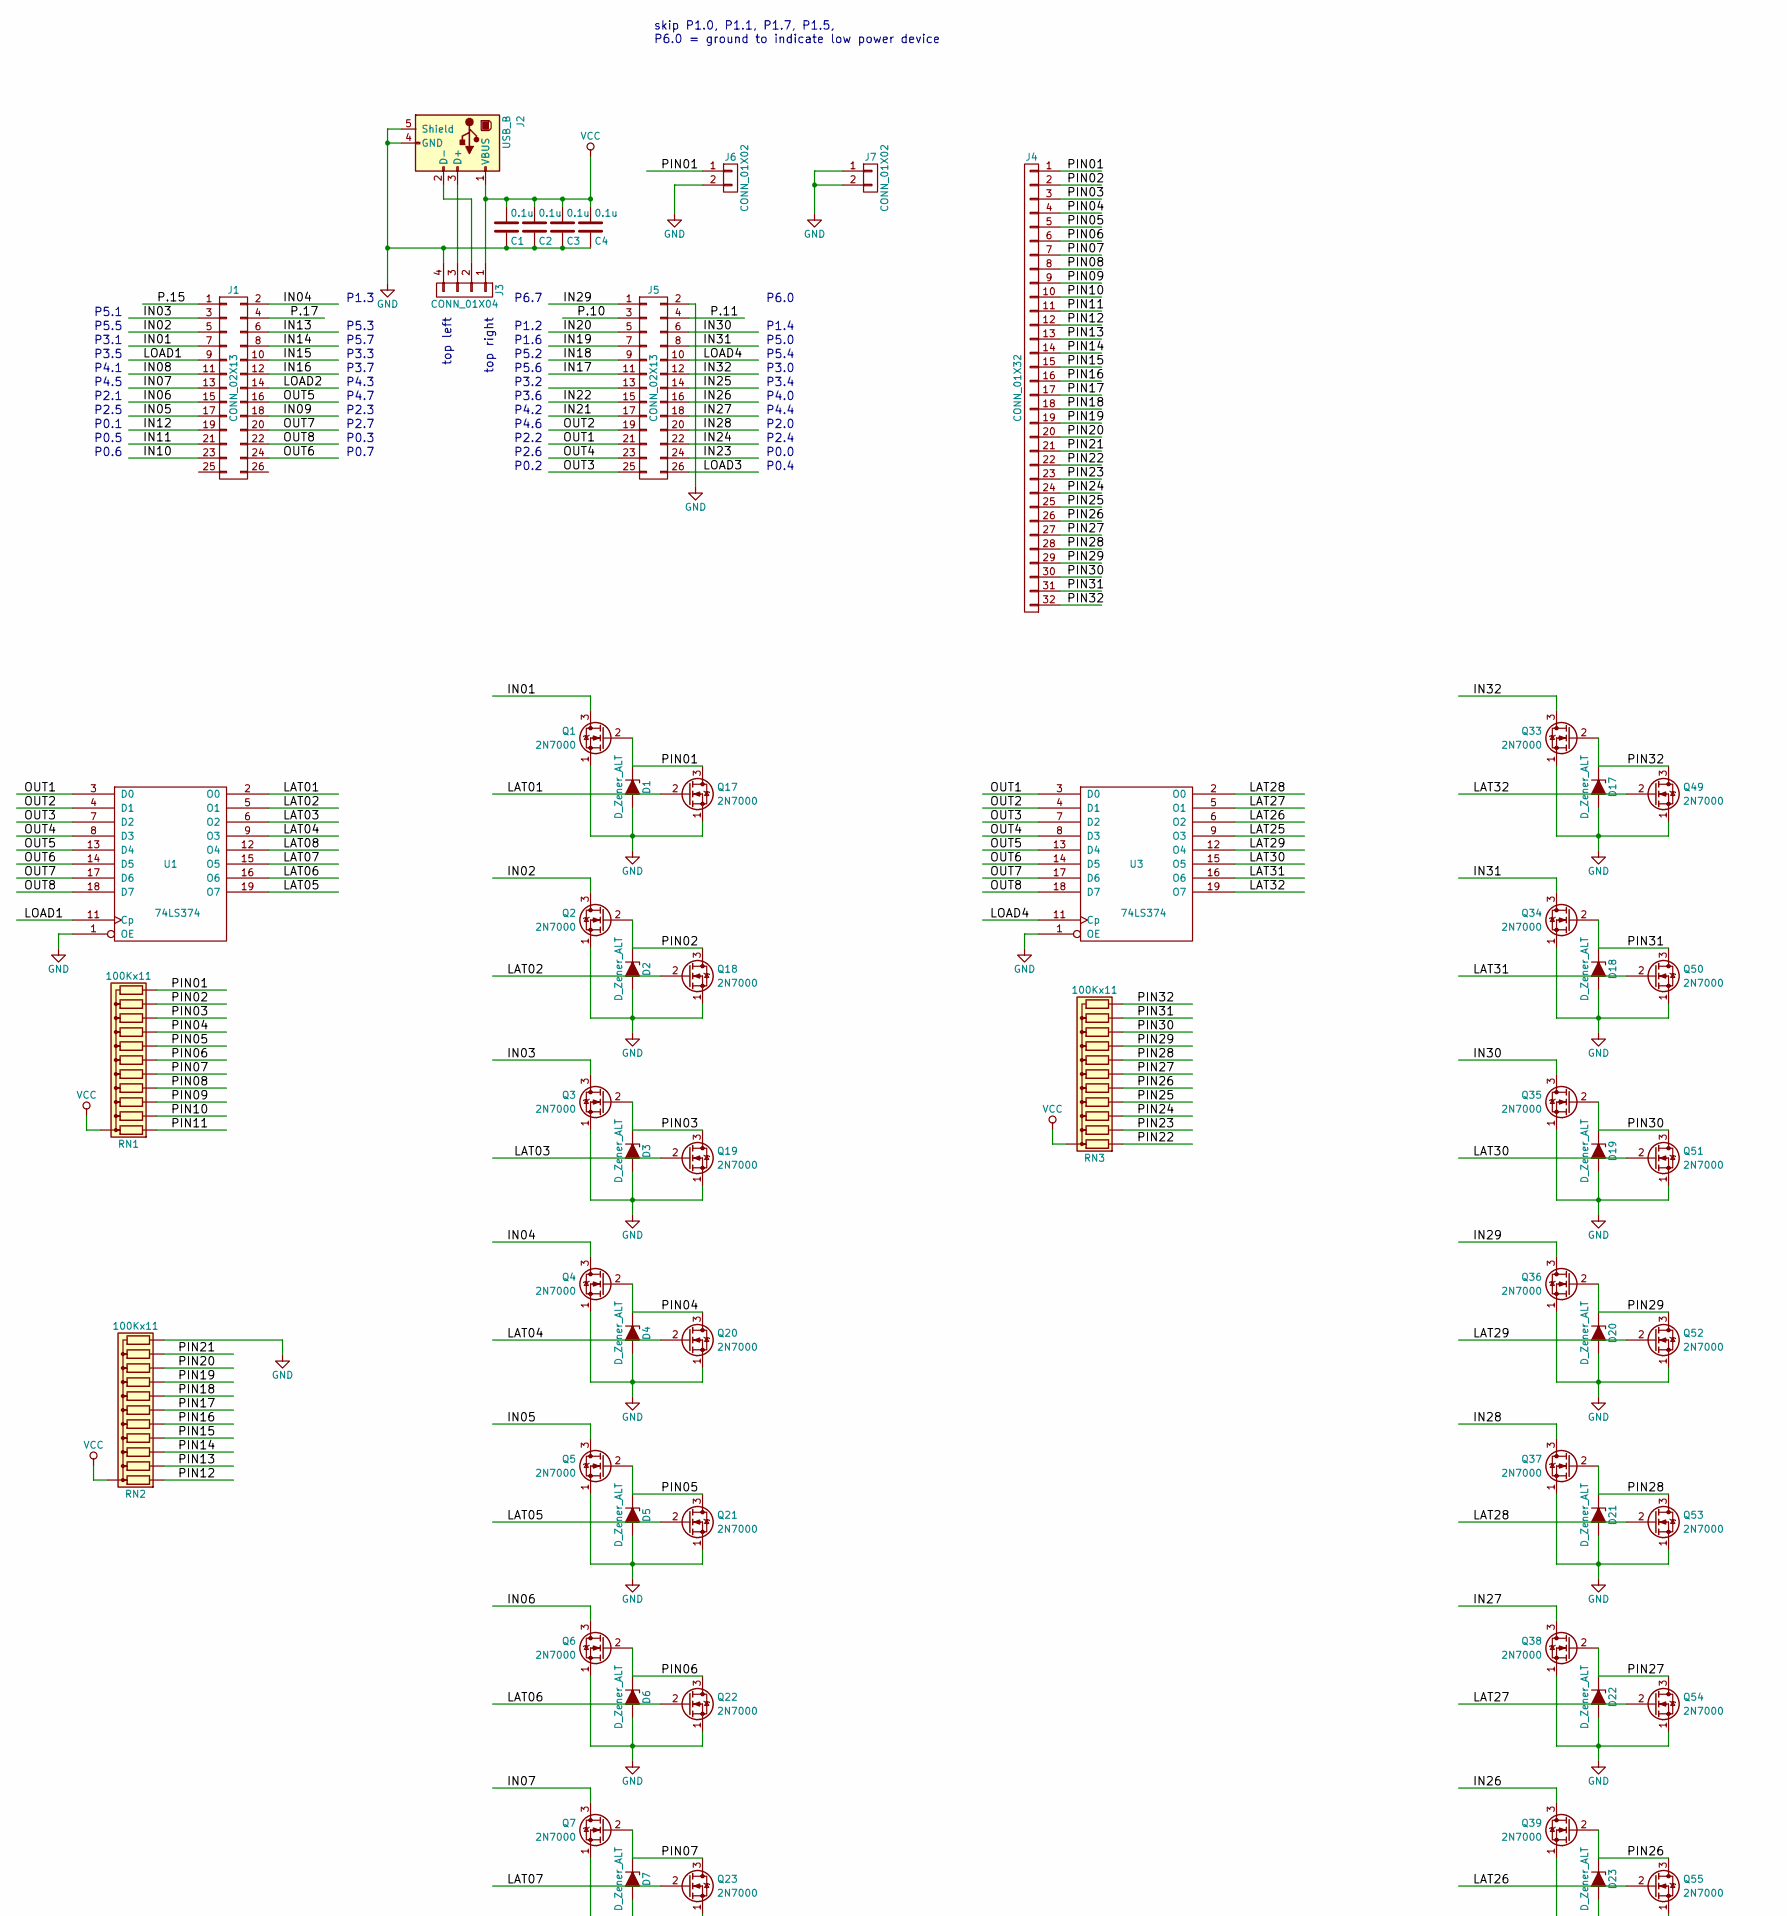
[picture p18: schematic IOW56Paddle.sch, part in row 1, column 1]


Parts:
C1, C2, C3, C4: 0.1u; C_Axial_L5.1mm_D3.1mm_P7.50mm_Horizontal
D1, D2, D3, D4, D5, D6, D7, D8, D9, D10, D11, D12, D13, D14, D15, D16, D17, D18, D19, D20, D21, D22, D23, D24, D25, D26, D27, D28, D29, D30, D31, D32: D_Zener_ALT; D_DO-35_SOD27_P6.35mm_Horizontal
J1, J5: CONN_02X13; Pin_Header_Straight_2x13_Pitch2.54mm
J2: USB_B
J3: CONN_01X04; Pin_Header_Straight_1x04_Pitch2.54mm
J4: CONN_01X32; Pin_Header_Straight_1x32_Pitch2.54mm
J6, J7: CONN_01X02; Pin_Header_Straight_1x02_Pitch2.54mm
Q1, Q2, Q3, Q4, Q5, Q6, Q7, Q8, Q9, Q10, Q11, Q12, Q13, Q14, Q15, Q16, Q17, Q18, Q19, Q20, Q21, Q22, Q23, Q24, Q25, Q26, Q27, Q28, Q29, Q30, Q31, Q32, Q33, Q34, Q35, Q36, Q37, Q38, Q39, Q40, Q41, Q42, Q43, Q44, Q45, Q46, Q47, Q48, Q49, Q50, Q51, Q52, Q53, Q54, Q55, Q56, Q57, Q58, Q59, Q60, Q61, Q62, Q63, Q64: 2N7000; TO-92_Molded_Wide
RN1, RN2, RN3: 100Kx11; R_Array_SIP12
U1, U2, U3, U4: 74LS374; DIP-20_W7.62mm

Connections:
/IN01: J1.7, Q1.3 (D)
/IN02: J1.5, Q2.3 (D)
/IN03: J1.3, Q3.3 (D)
/IN04: J1.2, Q4.3 (D)
/IN05: J1.17, Q5.3 (D)
/IN06: J1.15, Q6.3 (D)
/IN07: J1.13, Q7.3 (D)
/IN08: J1.11, Q8.3 (D)
/IN09: J1.18, Q9.3 (D)
/IN10: J1.23, Q10.3 (D)
/IN11: J1.21, Q11.3 (D)
/IN12: J1.19, Q12.3 (D)
/IN13: J1.6, Q13.3 (D)
/IN14: J1.8, Q14.3 (D)
/IN15: J1.10, Q15.3 (D)
/IN16: J1.12, Q16.3 (D)
/IN17: J5.11, Q48.3 (D)
/IN18: J5.9, Q47.3 (D)
/IN19: J5.7, Q46.3 (D)
/IN20: J5.5, Q45.3 (D)
/IN21: J5.17, Q44.3 (D)
/IN22: J5.15, Q43.3 (D)
/IN23: J5.24, Q42.3 (D)
/IN24: J5.22, Q41.3 (D)
/IN25: J5.14, Q40.3 (D)
/IN26: J5.16, Q39.3 (D)
/IN27: J5.18, Q38.3 (D)
/IN28: J5.20, Q37.3 (D)
/IN29: J5.1, Q36.3 (D)
/IN30: J5.6, Q35.3 (D)
/IN31: J5.8, Q34.3 (D)
/IN32: J5.12, Q33.3 (D)
/LAT01: Q17.2 (G), U1.2 (O0)
/LAT02: Q18.2 (G), U1.5 (O1)
/LAT03: Q19.2 (G), U1.6 (O2)
/LAT04: Q20.2 (G), U1.9 (O3)
/LAT05: Q21.2 (G), U1.19 (O7)
/LAT06: Q22.2 (G), U1.16 (O6)
/LAT07: Q23.2 (G), U1.15 (O5)
/LAT08: Q24.2 (G), U1.12 (O4)
/LAT09: Q25.2 (G), U2.2 (O0)
/LAT10: Q26.2 (G), U2.5 (O1)
/LAT11: Q27.2 (G), U2.6 (O2)
/LAT12: Q28.2 (G), U2.9 (O3)
/LAT13: Q29.2 (G), U2.19 (O7)
/LAT14: Q30.2 (G), U2.16 (O6)
/LAT15: Q31.2 (G), U2.15 (O5)
/LAT16: Q32.2 (G), U2.12 (O4)
/LAT17: Q64.2 (G), U4.9 (O3)
/LAT18: Q63.2 (G), U4.6 (O2)
/LAT19: Q62.2 (G), U4.5 (O1)
/LAT20: Q61.2 (G), U4.2 (O0)
/LAT21: Q60.2 (G), U4.12 (O4)
/LAT22: Q59.2 (G), U4.15 (O5)
/LAT23: Q58.2 (G), U4.16 (O6)
/LAT24: Q57.2 (G), U4.19 (O7)
/LAT25: Q56.2 (G), U3.9 (O3)
/LAT26: Q55.2 (G), U3.6 (O2)
/LAT27: Q54.2 (G), U3.5 (O1)
/LAT28: Q53.2 (G), U3.2 (O0)
/LAT29: Q52.2 (G), U3.12 (O4)
/LAT30: Q51.2 (G), U3.15 (O5)
/LAT31: Q50.2 (G), U3.16 (O6)
/LAT32: Q49.2 (G), U3.19 (O7)
/LOAD1: J1.9, U1.11 (Cp)
/LOAD2: J1.14, U2.11 (Cp)
/LOAD3: J5.26, U4.11 (Cp)
/LOAD4: J5.10, U3.11 (Cp)
/OUT1: J5.21, U1.3 (D0), U2.3 (D0), U3.3 (D0), U4.3 (D0)
/OUT2: J5.19, U1.4 (D1), U2.4 (D1), U3.4 (D1), U4.4 (D1)
/OUT3: J5.25, U1.7 (D2), U2.7 (D2), U3.7 (D2), U4.7 (D2)
/OUT4: J5.23, U1.8 (D3), U2.8 (D3), U3.8 (D3), U4.8 (D3)
/OUT5: J1.16, U1.13 (D4), U2.13 (D4), U3.13 (D4), U4.13 (D4)
/OUT6: J1.24, U1.14 (D5), U2.14 (D5), U3.14 (D5), U4.14 (D5)
/OUT7: J1.20, U1.17 (D6), U2.17 (D6), U3.17 (D6), U4.17 (D6)
/OUT8: J1.22, U1.18 (D7), U2.18 (D7), U3.18 (D7), U4.18 (D7)
/P.10: J5.3
/P.11: J5.4
/P.15: J1.1
/P.17: J1.4
/PIN01: D1.1 (K), J4.1, J6.1, Q1.2 (G), Q17.3 (D), RN1.12 (R11)
/PIN02: D2.1 (K), J4.2, Q2.2 (G), Q18.3 (D), RN1.11 (R10)
/PIN03: D3.1 (K), J4.3, Q3.2 (G), Q19.3 (D), RN1.10 (R9)
/PIN04: D4.1 (K), J4.4, Q4.2 (G), Q20.3 (D), RN1.9 (R8)
/PIN05: D5.1 (K), J4.5, Q5.2 (G), Q21.3 (D), RN1.8 (R7)
/PIN06: D6.1 (K), J4.6, Q6.2 (G), Q22.3 (D), RN1.7 (R6)
/PIN07: D7.1 (K), J4.7, Q7.2 (G), Q23.3 (D), RN1.6 (R5)
/PIN08: D8.1 (K), J4.8, Q8.2 (G), Q24.3 (D), RN1.5 (R4)
/PIN09: D9.1 (K), J4.9, Q9.2 (G), Q25.3 (D), RN1.4 (R3)
/PIN10: D10.1 (K), J4.10, Q10.2 (G), Q26.3 (D), RN1.3 (R2)
/PIN11: D11.1 (K), J4.11, Q11.2 (G), Q27.3 (D), RN1.2 (R1)
/PIN12: D12.1 (K), J4.12, Q12.2 (G), Q28.3 (D), RN2.2 (R1)
/PIN13: D13.1 (K), J4.13, Q13.2 (G), Q29.3 (D), RN2.3 (R2)
/PIN14: D14.1 (K), J4.14, Q14.2 (G), Q30.3 (D), RN2.4 (R3)
/PIN15: D15.1 (K), J4.15, Q15.2 (G), Q31.3 (D), RN2.5 (R4)
/PIN16: D16.1 (K), J4.16, Q16.2 (G), Q32.3 (D), RN2.6 (R5)
/PIN17: D32.1 (K), J4.17, Q48.2 (G), Q64.3 (D), RN2.7 (R6)
/PIN18: D31.1 (K), J4.18, Q47.2 (G), Q63.3 (D), RN2.8 (R7)
/PIN19: D30.1 (K), J4.19, Q46.2 (G), Q62.3 (D), RN2.9 (R8)
/PIN20: D29.1 (K), J4.20, Q45.2 (G), Q61.3 (D), RN2.10 (R9)
/PIN21: D28.1 (K), J4.21, Q44.2 (G), Q60.3 (D), RN2.11 (R10)
/PIN22: D27.1 (K), J4.22, Q43.2 (G), Q59.3 (D), RN3.2 (R1)
/PIN23: D26.1 (K), J4.23, Q42.2 (G), Q58.3 (D), RN3.3 (R2)
/PIN24: D25.1 (K), J4.24, Q41.2 (G), Q57.3 (D), RN3.4 (R3)
/PIN25: D24.1 (K), J4.25, Q40.2 (G), Q56.3 (D), RN3.5 (R4)
/PIN26: D23.1 (K), J4.26, Q39.2 (G), Q55.3 (D), RN3.6 (R5)
/PIN27: D22.1 (K), J4.27, Q38.2 (G), Q54.3 (D), RN3.7 (R6)
/PIN28: D21.1 (K), J4.28, Q37.2 (G), Q53.3 (D), RN3.8 (R7)
/PIN29: D20.1 (K), J4.29, Q36.2 (G), Q52.3 (D), RN3.9 (R8)
/PIN30: D19.1 (K), J4.30, Q35.2 (G), Q51.3 (D), RN3.10 (R9)
/PIN31: D18.1 (K), J4.31, Q34.2 (G), Q50.3 (D), RN3.11 (R10)
/PIN32: D17.1 (K), J4.32, Q33.2 (G), Q49.3 (D), RN3.12 (R11)
GND: C1.1, C2.1, C3.1, C4.1, D1.2 (A), D2.2 (A), D3.2 (A), D4.2 (A), D5.2 (A), D6.2 (A), D7.2 (A), D8.2 (A), D9.2 (A), D10.2 (A), D11.2 (A), D12.2 (A), D13.2 (A), D14.2 (A), D15.2 (A), D16.2 (A), D17.2 (A), D18.2 (A), D19.2 (A), D20.2 (A), D21.2 (A), D22.2 (A), D23.2 (A), D24.2 (A), D25.2 (A), D26.2 (A), D27.2 (A), D28.2 (A), D29.2 (A), D30.2 (A), D31.2 (A), D32.2 (A), J2.4 (GND), J2.5 (Shield), J3.4, J5.2, J6.2, J7.1, J7.2, Q1.1 (S), Q2.1 (S), Q3.1 (S), Q4.1 (S), Q5.1 (S), Q6.1 (S), Q7.1 (S), Q8.1 (S), Q9.1 (S), Q10.1 (S), Q11.1 (S), Q12.1 (S), Q13.1 (S), Q14.1 (S), Q15.1 (S), Q16.1 (S), Q17.1 (S), Q18.1 (S), Q19.1 (S), Q20.1 (S), Q21.1 (S), Q22.1 (S), Q23.1 (S), Q24.1 (S), Q25.1 (S), Q26.1 (S), Q27.1 (S), Q28.1 (S), Q29.1 (S), Q30.1 (S), Q31.1 (S), Q32.1 (S), Q33.1 (S), Q34.1 (S), Q35.1 (S), Q36.1 (S), Q37.1 (S), Q38.1 (S), Q39.1 (S), Q40.1 (S), Q41.1 (S), Q42.1 (S), Q43.1 (S), Q44.1 (S), Q45.1 (S), Q46.1 (S), Q47.1 (S), Q48.1 (S), Q49.1 (S), Q50.1 (S), Q51.1 (S), Q52.1 (S), Q53.1 (S), Q54.1 (S), Q55.1 (S), Q56.1 (S), Q57.1 (S), Q58.1 (S), Q59.1 (S), Q60.1 (S), Q61.1 (S), Q62.1 (S), Q63.1 (S), Q64.1 (S), RN2.12 (R11), U1.1 (OE), U1.10 (GND), U2.1 (OE), U2.10 (GND), U3.1 (OE), U3.10 (GND), U4.1 (OE), U4.10 (GND)
unnamed: J2.2 (D-), J3.2
unnamed: J2.3 (D+), J3.3
VCC: C1.2, C2.2, C3.2, C4.2, J2.1 (VBUS), J3.1, RN1.1 (common), RN2.1 (common), RN3.1 (common), U1.20 (VCC), U2.20 (VCC), U3.20 (VCC), U4.20 (VCC)

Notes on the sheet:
top right
top left
skip P1.0, P1.1, P1.7, P1.5, P6.0 = ground to indicate low power device
P5.1
P5.5
P3.1
P3.5
P4.1
P4.5
P2.1
P2.5
P0.1
P0.5
P0.6
P1.3
P5.3
P5.7
P3.3
P3.7
P4.3
P4.7
P2.3
P2.7
P0.3
P0.7
P6.7
P1.2
P1.6
P5.2
P5.6
P3.2
P3.6
P4.2
P4.6
P2.2
P2.6
P0.2
P6.0
P1.4
P5.0


Board: 4 copper layers, 83.8 x 182.9 mm, 114 parts (0 on the bottom side), 112 nets.

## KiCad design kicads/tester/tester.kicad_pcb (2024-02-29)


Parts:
C1, C2, C3, C4, C5, C6: 0.1u; C_Axial_0.1uF
D1, D2, D3, D4, D5, D7: 1N4148; D_DO-35_SOD27_P7.62mm_Horizontal
D6: 3.0V; D_DO-35_SOD27_P7.62mm_Horizontal
J1: CONN_01X03; Pin_Header_Straight_1x06_Pitch2.54mm
J2, J3, J4, J5, J8: CONN_01X03; Pin_Header_Straight_1x03_Pitch2.54mm
J6, J7: CONN_01X01; Pin_Header_Straight_1x01_Pitch2.54mm
Q1, Q2: 2N3904; TO-92_Molded_Wide
R1: 220; R_Axial_QtrWatt
R2, R8: 47K; R_Axial_QtrWatt
R3, R9: 150K; R_Axial_QtrWatt
R4, R5, R10, R11: 26.7K; R_Axial_QtrWatt
R6, R12: 46.4K; R_Axial_QtrWatt
R7, R13: 4.7K; R_Axial_QtrWatt
R14, R15: 10K; R_Axial_QtrWatt
R16, R18: 1K; R_Axial_QtrWatt
R17, R19: 68K; R_Axial_QtrWatt
U1: 6J6; B7G-0.7dia

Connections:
/+3V: C4.1, D6.1 (K), R1.1, U1.7 (K)
/+5V: C2.1, J1.3, R1.2, R2.1, R7.1, R8.1, R13.1, R16.1, R17.1, R18.1, R19.1
/+120V: C1.1, J1.1, R4.1, R10.1
/-96V: C3.2, J1.6, R6.2, R12.2
/VF1: J5.1, R14.1, U1.4 (F1)
/VF2: J5.3, R15.1, U1.3 (F2)
unnamed: C5.1, Q2.2 (B), R17.2
unnamed: C5.2, J2.1, J2.2, Q1.3 (C), R16.2
unnamed: C6.1, Q1.2 (B), R19.2
unnamed: C6.2, J8.1, J8.2, Q2.3 (C), R18.2
unnamed: D1.1 (K), J3.1
unnamed: D1.2 (A), D2.2 (A), R2.2
unnamed: D2.1 (K), J3.2, R3.1, U1.6 (G)
unnamed: D3.1 (K), J3.3, R5.2, R6.1
unnamed: D3.2 (A), R7.2
unnamed: D4.1 (K), J4.1
unnamed: D4.2 (A), D5.2 (A), R8.2
unnamed: D5.1 (K), J4.2, R9.1, U1.5 (G)
unnamed: D7.1 (K), J4.3, R11.2, R12.1
unnamed: D7.2 (A), R13.2
unnamed: R4.2, R5.1, U1.1 (A)
unnamed: R10.2, R11.1, U1.2 (A)

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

Board: 4 copper layers, 101.6 x 82.5 mm, 43 parts (0 on the bottom side), 23 nets.

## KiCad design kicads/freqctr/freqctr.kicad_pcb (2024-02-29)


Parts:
C1: 0.1u; C_Axial_L3.8mm_D2.6mm_P7.50mm_Horizontal
D1, D2, D3, D4, D5: 5082-7750; DIP-14_W7.62mm
J1, J2: Conn_01x15_Pin; PinHeader_1x15_P2.54mm_Vertical
J3: Conn_01x03_Pin; PinHeader_1x03_P2.54mm_Vertical
Q1, Q2, Q3, Q4, Q5: 2N3904; TO-92_Inline_Wide
R1, R2, R3, R4, R5, R6, R7: 150; R_Axial_DIN0207_L6.3mm_D2.5mm_P5.08mm_Vertical

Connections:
GND: C1.2, J1.14, J2.12, J3.2
unnamed: D1.1 (a), D2.1 (a), D3.1 (a), D4.1 (a), D5.1 (a), R1.1
unnamed: D1.13 (b), D2.13 (b), D3.13 (b), D4.13 (b), D5.13 (b), R2.1
unnamed: D1.10 (c), D2.10 (c), D3.10 (c), D4.10 (c), D5.10 (c), R3.1
unnamed: D1.8 (d), D2.8 (d), D3.8 (d), D4.8 (d), D5.8 (d), R4.1
unnamed: D1.7 (e), D2.7 (e), D3.7 (e), D4.7 (e), D5.7 (e), R5.1
unnamed: D1.2 (f), D2.2 (f), D3.2 (f), D4.2 (f), D5.2 (f), R6.1
unnamed: D1.11 (g), D2.11 (g), D3.11 (g), D4.11 (g), D5.11 (g), R7.1
unnamed: D1.14 (x), Q1.1 (E)
unnamed: D2.14 (x), Q2.1 (E)
unnamed: D3.14 (x), Q3.1 (E)
unnamed: D4.14 (x), Q4.1 (E)
unnamed: D5.14 (x), Q5.1 (E)
unnamed: J1.10, Q1.2 (B)
unnamed: J1.11, J3.3
unnamed: J2.1, Q5.2 (B)
unnamed: J2.2, R1.2
unnamed: J2.3, Q4.2 (B)
unnamed: J2.4, R2.2
unnamed: J2.5, R6.2
unnamed: J2.6, Q3.2 (B)
unnamed: J2.7, R7.2
unnamed: J2.8, R3.2
unnamed: J2.9, Q2.2 (B)
unnamed: J2.10, R4.2
unnamed: J2.11, R5.2
VCC: C1.1, J1.12, J3.1, Q1.3 (C), Q2.3 (C), Q3.3 (C), Q4.3 (C), Q5.3 (C)



Board: 2 copper layers, 68.6 x 50.8 mm, 21 parts (16 on the bottom side), 27 nets.

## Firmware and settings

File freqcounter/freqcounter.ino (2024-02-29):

// Runs on Arduino Nano Every to act as frequency counter
// It is connected to 5 7-segment displays able to measure frequencies from 0 to 65535 cps

//               SCK  PE2    D13   L-1   R-1   D12    PE1  MISO (SC1)   DIG_4_PIN
//                         +3.3V   L-2   R-2   D11    PE0  MOSI (SC1)   SEG_A_PIN
//                    PD7   AREF   L-3   R-3   D10    PB1               DIG_3_PIN
//             AIN[3] PD3 A0/D14   L-4   R-4   D9     PB0               SEG_B_PIN
//             AIN[2] PD2 A1/D15   L-5   R-5   D8     PE3               SEG_F_PIN
//             AIN[1] PD1 A2/D16   L-6   R-6   D7     PA1               DIG_2_PIN
//             AIN[0] PD0 A3/D17   L-7   R-7   D6     PF4               SEG_G_PIN
//               SDA  PA2 A4/D18   L-8   R-8   D5     PB2               SEG_C_PIN
//               SCL  PA3 A5/D19   L-9   R-9   D4     PC6               DIG_1_PIN
//  DIG_0_PIN  AIN[4] PD4 A6/D20  L-10   R-10  D3     PF5               SEG_D_PIN
//  INPUT_PIN  AIN[5] PD5 A7/D21  L-11   R-11  D2     PA0               SEG_E_PIN
//                           +5V  L-12   R-12  GND
//                        _RESET  L-13   R-13  _RESET
//                           GND  L-14   R-14  RX     PC5
//                           VIN  L-15   R-15  TX     PC4

#define INPUT_PIN 21    // L-11
#define SEG_A_PIN 11    // R-2    R1     top
#define SEG_B_PIN 9     // R-4    R2     upper right
#define SEG_C_PIN 5     // R-8    R3     lower right
#define SEG_D_PIN 3     // R-10   R4     bottom
#define SEG_E_PIN 2     // R-11   R5     lower left
#define SEG_F_PIN 8     // R-5    R6     upper left
#define SEG_G_PIN 6     // R-7    R7     center
#define DIG_0_PIN 20    // L-10   Q1/D1  10**0
#define DIG_1_PIN 4     // R-9    Q2/D2  10**1
#define DIG_2_PIN 7     // R-6    Q3/D3  10**2
#define DIG_3_PIN 10    // R-3    Q4/D4  10**3
#define DIG_4_PIN 12    // R-1    Q5/D5  10**4

#define UPDPERSEC 5     // update frequency reading this many times per second (exact)
#define DISPLAYHZ 60    // refresh each digit this many times per second (approx)
#define NUMDIGITS 5     // total number of digits

#define DOWNSIDEUP 1

#define EVENSPLIT ((1000000 % UPDPERSEC) == 0)
#if EVENSPLIT
#define MICROSPERUPD (1000000 / UPDPERSEC)
#else
#define MICROSPERUPD updatemicros[updateindex]
#endif

bool ledison;
uint8_t lastsegments;
uint16_t volatile interruptcounter;
uint16_t updateindex;
uint16_t maincounters[UPDPERSEC];
uint16_t totalcount;
uint32_t lastdisplaymicros;
uint32_t lastsamplemicros;
#if ! EVENSPLIT
uint32_t updatemicros[UPDPERSEC];
#endif

uint8_t const digpins[NUMDIGITS] = {
#if DOWNSIDEUP
  DIG_4_PIN, DIG_3_PIN, DIG_2_PIN, DIG_1_PIN, DIG_0_PIN
#else
  DIG_0_PIN, DIG_1_PIN, DIG_2_PIN, DIG_3_PIN, DIG_4_PIN
#endif
};
uint8_t const segpins[7] = {
#if DOWNSIDEUP
  SEG_D_PIN, SEG_E_PIN, SEG_F_PIN, SEG_A_PIN, SEG_B_PIN, SEG_C_PIN, SEG_G_PIN
#else
  SEG_A_PIN, SEG_B_PIN, SEG_C_PIN, SEG_D_PIN, SEG_E_PIN, SEG_F_PIN, SEG_G_PIN
#endif
};
uint8_t const digtosegs[10] = { 0x3F, 0x06, 0x5B, 0x4F, 0x66, 0x6D, 0x7D, 0x07, 0x7F, 0x67 };
uint8_t digsegs[NUMDIGITS];
uint8_t scandigit;

void freqPinInterrupt ();

void setup() {

  pinMode (LED_BUILTIN, OUTPUT);

  // turns on segment when LOW
  for (uint16_t seg = 0; seg < 7; seg ++) {
    pinMode (segpins[seg], OUTPUT);
  }

  // turns on digit when HIGH
  for (uint16_t dig = 0; dig < NUMDIGITS; dig ++) {
    pinMode (digpins[dig], OUTPUT);
    // turn on all segments for all digits when the loop() executes until first sample taken
    digsegs[dig] = 0x7F;
  }

  // microseconds between frequency reading updates
#if ! EVENSPLIT
  uint32_t accummicros = 0;
  for (uint16_t i = 0; i < UPDPERSEC; i ++) {
    uint32_t totalmicros = 1000000 * (i + 1) / UPDPERSEC;
    updatemicros[i] = totalmicros - accummicros;
    accummicros = totalmicros;
  }
#endif

  pinMode (INPUT_PIN, INPUT);
  attachInterrupt (digitalPinToInterrupt (INPUT_PIN), freqPinInterrupt, RISING);

  Serial.begin(9600);

  lastdisplaymicros = lastsamplemicros = micros ();

  memset(maincounters, 0, sizeof maincounters);
  totalcount = 0;
}

void loop() {
  uint32_t thismicros = micros ();

  // see if it's time to turn off one digit and turn on the next
  if (thismicros - lastdisplaymicros >= 1000000 / (NUMDIGITS * DISPLAYHZ)) {
    lastdisplaymicros += 1000000 / (NUMDIGITS * DISPLAYHZ);
    digitalWrite (digpins[scandigit], LOW);       // turn off previous digit
    if (++ scandigit == NUMDIGITS) scandigit = 0; // increment on to next digit
    uint8_t segments = digsegs[scandigit];        // get segments for next digit
    uint8_t updates  = segments ^ lastsegments;   // see which segments need to be updated
    lastsegments = segments;
    uint8_t seg = 0;                              // start with updating segment 'a'
    while (updates > 0) {                         // loop as long as more to update
      if (updates & 1) {                          // spend time updating if different
        digitalWrite (segpins[seg], (segments & 1) ? LOW : HIGH);
      }
      seg ++;                                     // on to next segment
      segments /= 2;
      updates  /= 2;
    }
    digitalWrite (digpins[scandigit], HIGH);      // turn digit on
  }

  // sample interrupt count exactly UPDPERSEC times per second
  if (thismicros - lastsamplemicros >= MICROSPERUPD) {
    // set up for next sample
    lastsamplemicros += MICROSPERUPD;
    // grab interrupt count and reset it
    noInterrupts();
    uint16_t thiscount = interruptcounter;
    interruptcounter = 0;
    interrupts();
    // update total count for the past second
    totalcount += thiscount - maincounters[updateindex];
    maincounters[updateindex] = thiscount;
    if (++ updateindex == UPDPERSEC) updateindex = 0;
    Serial.println(totalcount);
    // fill in at least 1 and up to 5 digits
    uint16_t count = totalcount;
    uint16_t i = 0;
    do {
      uint16_t dig = count % 10;
      digsegs[i++] = digtosegs[dig];
      count /= 10;
    } while ((i < NUMDIGITS) && (count > 0));
    // blank fill upper digits
    while (i < NUMDIGITS) digsegs[i++] = 0;
    // toggle the on-board LED
    ledison ^= true;
    digitalWrite (LED_BUILTIN, ledison ? HIGH : LOW);
  }
}

void freqPinInterrupt ()
{
  interruptcounter ++;
}

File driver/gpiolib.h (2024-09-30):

//    Copyright (C) Mike Rieker, Beverly, MA USA
//    www.outerworldapps.com
//
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
//    EXPECT it to FAIL when someone's HeALTh or PROpeRTy is at RISk.
//
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
//    http://www.gnu.org/licenses/gpl-2.0.html

#ifndef _GPIOLIB_H
#define _GPIOLIB_H

#include <netinet/in.h>
#include <pthread.h>
#include <signal.h>
#include <stdint.h>
#include <stdio.h>
#include <string>

#define DEFADDHZ 20000  // seems happy with vpp=117.3, vgg=-87.3
#define DEFCPUHZ 32000  // ...giving raspictl -randmem => 25340 Hz

#define G_CLOCK       0x4   // GPIO[02]   out: send clock signal to cpu
#define G_RESET       0x8   // GPIO[03]   out: send reset signal to cpu
#define G_DATA     0xFFF0   // GPIO[15:04] bi: data bus bits
#define G_LINK    0x10000   // GPIO[16]    bi: link bus bit
#define G_IOS     0x20000   // GPIO[17]   out: skip next instruction (valid in IOT.2 only)
#define G_TRIG    0x40000   // GPIO[18]   out: trigger scope
#define G_QENA    0x80000   // GPIO[19]   out: we are sending data out to cpu
#define G_IRQ    0x100000   // GPIO[20]   out: send interrupt request to cpu
#define G_DENA   0x200000   // GPIO[21]   out: we are receiving data from cpu
#define G_JUMP   0x400000   // GPIO[22]    in: doing JMP/JMS instruction
#define G_IOIN   0x800000   // GPIO[23]    in: I/O instruction (in state IOT.1)
#define G_DFRM  0x1000000   // GPIO[24]    in: accompanying READ and/or WRITE address uses data frame
#define G_READ  0x2000000   // GPIO[25]    in: cpu wants to read from us
#define G_WRITE 0x4000000   // GPIO[26]    in: cpu wants to write to us
#define G_IAK   0x8000000   // GPIO[27]    in: interrupt acknowledge

#define G_OUTS  (G_CLOCK|G_RESET|G_IOS|G_IRQ|G_DENA|G_QENA|G_TRIG)  // these are always output pins
#define G_INS   (G_IOIN|G_DFRM|G_JUMP|G_READ|G_WRITE|G_IAK)         // these are always input pins
#define G_DATA0 (G_DATA & -G_DATA)                                  // low-order data pin
#define G_ALL   (G_OUTS | G_INS | G_DATA | G_LINK)                  // all the gpio bits we care about

#define G_REVIS (G_IOIN)                                    // reverse these input pins when reading GPIO connector so app sees only active high signals
            // G_DATA  = _MD = _aluq: active low by alu.mod -> inverted by level converter -> active high to gpio connector -> active high to app
            // G_LINK  = _MDL = _lnq: active low by acl.mod -> inverted by level converter -> active high to gpio connector -> active high to app
            // G_IOIN  = active high by seq.mod -> inverted by level converter -> active low to gpio connector -> inverted by G_REVIS -> active high to app
            // G_DFRM  = active low by seq.mod -> inverted by level converter -> active high to gpio connector -> active high to app
            // G_JUMP  = active low by seq.mod -> inverted by level converter -> active high to gpio connector -> active high to app
            // G_READ  = active low by seq.mod -> inverted by level converter -> active high to gpio connector -> active high to app
            // G_WRITE = active low by seq.mod -> inverted by level converter -> active high to gpio connector -> active high to app
            // G_IAK   = active low by seq.mod -> inverted by level converter -> active high to gpio connector -> active high to app

#define G_REVOS (G_CLOCK|G_RESET|G_DATA|G_LINK|G_IOS|G_IRQ) // reverse these output pins when writing GPIO connector
            // G_CLOCK = active high by app -> inverted by G_REVOS -> active low on gpio connector -> inverted by level converter -> CLOK2 active high signal
            // G_RESET = active high by app -> inverted by G_REVOS -> active low on gpio connector -> inverted by level converter -> RESET active high signal
            // G_DATA  = active high by app -> inverted by G_REVOS -> active low on gpio connector -> inverted by level converter -> MQ active high signal
            // G_LINK  = active high by app -> inverted by G_REVOS -> active low on gpio connector -> inverted by level converter -> MQL active high signal
            // G_IOS   = active high by app -> inverted by G_REVOS -> active low on gpio connector -> inverted by level converter -> IOSKP active high signal
            // G_IRQ   = active high by app -> inverted by G_REVOS -> active low on gpio connector -> inverted by level converter -> INTRQ active high signal

struct GpioLib;
struct Shadow;

#include "abcd.h"
#include "miscdefs.h"
#include "myiowkit.h"

struct GpioFile {
    GpioFile ();
    virtual ~GpioFile ();
    void *open (char const *devname);
    void close ();

private:
    int memfd;
    void *memptr;
};

// base class for GPIO access
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

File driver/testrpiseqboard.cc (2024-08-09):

//    Copyright (C) Mike Rieker, Beverly, MA USA
//    www.outerworldapps.com
//
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
//    EXPECT it to FAIL when someone's HeALTh or PROpeRTy is at RISk.
//
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
//    http://www.gnu.org/licenses/gpl-2.0.html

/**
 * Program runs on the raspberry pi to control the computer.
 * Can also be run on a zynq for testing the test program.
 *
 *  export addhz=<addhz>
 *  export cpuhz=<cpuhz>
 *  ./testrpiseqboard [-csrclib] [-paddles] [-resetonerror] [-verbose] [-zynqlib]
 *
 *       <addhz> : specify cpu frequency for add cycles (default cpuhz Hz)
 *       <cpuhz> : specify cpu frequency for all other cycles (default DEFCPUHZ Hz)
 *
 *      -paddles : paddles are connected up
 *      -resetonerror : reset on error (otherwise abort on error)
 *      -verbose : print information each cycle
 *      -zynqlib : running on Zynq with circuit loaded
 */

#include <errno.h>
#include <fcntl.h>
#include <map>
#include <math.h>
#include <pthread.h>
#include <sched.h>
#include <signal.h>
#include <stdarg.h>
#include <stdio.h>
#include <stdlib.h>
#include <string.h>
#include <sys/file.h>
#include <sys/mman.h>
#include <sys/time.h>
#include <time.h>
#include <unistd.h>

#include "abcd.h"
#include "gpiolib.h"
#include "miscdefs.h"
#include "pindefs.h"
#include "rdcyc.h"

#define NSAVEDCYCLES 16

enum State {
    RESET1, FETCH1, FETCH2, DEFER1, DEFER2, DEFER3, INTAK1,
    AND1, AND2, TAD1, TAD2, TAD3, ISZ1, ISZ2, ISZ3, DCA1,
    DCA2, JMS1, JMS2, JMS3, JMP1, JMP2, IOT1, IOT2, GRP1
};

struct SavedCycle {
    uint64_t cycleno;
    uint32_t gpiocon;
    State state;
};

static pthread_t mintimestid;
static pthread_cond_t mintimescond = PTHREAD_COND_INITIALIZER;
static pthread_mutex_t mintimeslock = PTHREAD_MUTEX_INITIALIZER;

bool aborting;
bool paddles;
bool resetonerror;
bool verbose;
GpioLib *gpio;
SavedCycle savedcycles[NSAVEDCYCLES];
State state;
uint32_t syncintreq;
uint64_t cyclecount;

static void endofcycle ();
static bool verifygpio (uint32_t sample, uint32_t expect);
static char const *statestr (State s);
static uint16_t randuint16 (int nbits);
static void *mintimesthread (void *dummy);
static void sighandler (int signum);
static void exithandler ();

int main (int argc, char **argv)
{
    bool csrclib = false;
    bool zynqlib = false;

    setlinebuf (stdout);

    for (int i = 0; ++ i < argc;) {
        if (strcasecmp (argv[i], "-csrclib") == 0) {
            csrclib = true;
            zynqlib = false;
            continue;
        }
        if (strcasecmp (argv[i], "-paddles") == 0) {
            paddles = true;
            continue;
        }
        if (strcasecmp (argv[i], "-resetonerror") == 0) {
            resetonerror = true;
            continue;
        }
        if (strcasecmp (argv[i], "-verbose") == 0) {
            verbose = true;
            continue;
        }
        if (strcasecmp (argv[i], "-zynqlib") == 0) {
            csrclib = false;
            zynqlib = true;
            continue;
        }
        fprintf (stderr, "unknown argument %s\n", argv[i]);
        return 1;
    }

    // access cpu circuitry
    // either physical circuit (tubes or de0) via gpio pins
    // ...or zynq fpga circuit
    gpio = csrclib ? (GpioLib *) new CSrcLib ("rpiseq") : zynqlib ? (GpioLib *) new ZynqLib ("rpiseq") : (GpioLib *) new PhysLib ();
    gpio->open ();

    // always call haspads() so it can float the paddles
    if (! gpio->haspads () && paddles) {
        fprintf (stderr, "-paddles given but no paddles present\n");
        return 1;
    }

    // if paddles present, clamp acqzero to zero so we will get TAD states
    if (paddles) {
        uint32_t masks[NPADS], pinss[NPADS];
        memset (masks, -1, sizeof masks);
        memset (pinss, -1, sizeof pinss);
        pinss[1] = ~ B_acqzero;
        gpio->writepads (masks, pinss);
    }

    // print cpu cyclecount once per minute
    setmintimes (true);

    // catch normal termination signals to clean up
    signal (SIGABRT, sighandler);
    signal (SIGHUP,  sighandler);
    signal (SIGINT,  sighandler);
    signal (SIGTERM, sighandler);

    atexit (exithandler);

    // reset cpu circuit
resetit:;
    gpio->writegpio (false, G_RESET);
    gpio->halfcycle (false);
    gpio->halfcycle (false);
    gpio->halfcycle (false);

    uint16_t opcode = 0;
    state = RESET1;

    while (! aborting) {

        // drop clock (or reset) then wait half cycle to end of cycle
        gpio->writegpio (false, syncintreq);
        gpio->halfcycle (false);

        // that cycle is now complete
        endofcycle ();

        // invariant:
        //  clock has been low for half cycle in state given by 'state' variable
        //  G_DENA has been asserted for half cycle so we can read MDL,MD coming from tubes

        // get input signals from tubes just before raising clock
        uint32_t sample = gpio->readgpio () & G_ALL;
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

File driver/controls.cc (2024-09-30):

//    Copyright (C) Mike Rieker, Beverly, MA USA
//    www.outerworldapps.com
//
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
//    EXPECT it to FAIL when someone's HeALTh or PROpeRTy is at RISk.
//
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
//    http://www.gnu.org/licenses/gpl-2.0.html

// processor control functions
// - tell raspictl.cc main loop to stop, reset, run, step

#include <pthread.h>
#include <string.h>
#include <tcl.h>

#include "controls.h"
#include "memext.h"
#include "miscdefs.h"
#include "shadow.h"

// stop processor if not already
// - tells raspictl.cc main to suspend clocking the processor
// - stops in middle of a cycle with clock still high
// returns true: was already stopped
//        false: was running, now stopped
bool ctl_stop ()
{
    bool sigint = ctl_lock ();
    if (stopflags & SF_STOPPED) {

        // must be in middle of cycle with clock still high
        uint32_t sample = gpio->readgpio ();
        ASSERT (sample & G_CLOCK);

        ctl_unlock (sigint);
        return true;
    }

    // if nothing else has requested stop, request stop and say because of stop button
    if (! (stopflags & SF_STOPIT)) {
        stopreason = "STOPBUTTON";
        stopflags |= SF_STOPIT;
    }

    // if raspictl.cc main sleeping in an WFI instruction, wake it up
    wfiwake ();

    // wait for raspictl.cc main to stop cycling processor
    while (! (stopflags & SF_STOPPED)) {
        pthread_cond_wait (&stopcond2, &stopmutex);
    }

    // must be in middle of cycle with clock still high
    uint32_t sample = gpio->readgpio ();
    ASSERT (sample & G_CLOCK);

    ctl_unlock (sigint);
    return false;
}

// flag processor to stop for the given reason
// does not wait for processor to stop
bool ctl_stopfor (char const *reason)
{
    bool sigint = ctl_lock ();
    if (stopflags & SF_STOPIT) {
        ctl_unlock (sigint);
        return true;
    }

    // if nothing else has requested stop, request stop and say because of stop button
    stopreason = reason;
    stopflags |= SF_STOPIT;

    // if raspictl.cc main sleeping in an WFI instruction, wake it up
    wfiwake ();

    ctl_unlock (sigint);
    return false;
}

bool ctl_isstopped ()
{
    return (stopflags & SF_STOPPED) != 0;
}

// reset processor
// returns with processor stopped in middle of FETCH2 with clock still high
// ...and with DF,IF,PC set to the given 15-bit address
// returns false: processor running on entry, still running
//          true: processor was stopped on entry, now stopped in FETCH2
bool ctl_reset (uint16_t addr, bool resio)
{
    bool sigint = ctl_lock ();

    // processor must already be stopped
    if (! (stopflags & SF_STOPPED)) {
        ctl_unlock (sigint);
        return false;
    }

    // tell it what 15-bit address to reset to
    startpc = addr & 077777;
    resetio = resio;

    // tell main to reset but then stop immediately thereafter
    stopreason = "RESETBUTTON";
    stopflags  = SF_STOPIT | SF_RESETIT;
    stopwake ();

    // wait for raspictl.cc main to finish resetting
    while (! (stopflags & SF_STOPPED)) {
        pthread_cond_wait (&stopcond2, &stopmutex);
    }

    // raspictl.cc main has reset the processor and the tubes are waiting in the middle of FETCH2 with the clock still high
    // when resumed, raspictl.cc main will drive the clock low and resume processing from there
    ASSERT (shadow.r.state == Shadow::State::FETCH2);
    ASSERT (memext.iframe == (addr & 070000));
    ASSERT (memext.dframe == (addr & 070000));

    ctl_unlock (sigint);

    return true;
}

// tell processor to start running
// - tells raspictl.cc main to resume clocking the processor
bool ctl_run ()
{
    bool sigint = ctl_lock ();

    // maybe already running
    if (! (stopflags & SF_STOPPED)) {
        ctl_unlock (sigint);
        return false;
    }

    // maybe control-C was just pressed
    if (ctrlcflag) {
        stopreason = "CONTROL_C";
        ctl_unlock (sigint);
        return true;
    }

    // clock must be high (assumed by raspictl.cc stopped())
    uint32_t sample = gpio->readgpio ();
    ASSERT (sample & G_CLOCK);

    // tell raspictl.cc stopped() to resume cycling the processor
    stopreason = "";
    stopflags  = 0;
    stopwake ();
    ctl_unlock (sigint);
    return true;
}

// tell processor to step one cycle
// - tells raspictl.cc main to clock the processor a single cycle
// - stops in middle of next cycle with clock still high
bool ctl_stepcyc ()
{
    bool sigint = ctl_lock ();

    // processor must already be stopped
    if (! (stopflags & SF_STOPPED)) {
        ctl_unlock (sigint);
        return false;
    }

    // clock must be high (assumed by raspictl.cc stopped())
    uint32_t sample = gpio->readgpio ();
    ASSERT (sample & G_CLOCK);

    // tell it to start, run one cycle, then stop
    stopreason = "";
    stopflags  = SF_STOPIT;
    stopwake ();

    // wait for it to stop again
    while (! (stopflags & SF_STOPPED)) {
        pthread_cond_wait (&stopcond2, &stopmutex);
    }

    // clock should be high
    sample = gpio->readgpio ();
    ASSERT (sample & G_CLOCK);

    // if normal stop, say it's because of stepping
    if (stopreason[0] == 0) {
        stopreason = "SINGLECYCLE";
    }

    ctl_unlock (sigint);
    return true;
}

// tell processor to step one instruction
// - tells raspictl.cc main to clock the processor a single cycle
// - stops at the end of the next FETCH2 or INTAK1 cycle
bool ctl_stepins ()
{
    bool sigint = ctl_lock ();

    // processor must already be stopped
    if (! (stopflags & SF_STOPPED)) {
        ctl_unlock (sigint);
        return false;
    }

    // clock must be high (assumed by raspictl.cc stopped())
    uint32_t sample = gpio->readgpio ();
    ASSERT (sample & G_CLOCK);

    do {

        // tell it to start, run one cycle, then stop
        stopreason = "";
        stopflags  = SF_STOPIT;
        stopwake ();

        // wait for it to stop again
        while (! (stopflags & SF_STOPPED)) {
            pthread_cond_wait (&stopcond2, &stopmutex);
        }

        // clock should be high
        sample = gpio->readgpio ();
        ASSERT (sample & G_CLOCK);

        // stop if some error
        if (stopreason[0] != 0) break;

        // repeat until fetching next instruction
    } while ((shadow.r.state != Shadow::State::FETCH2) && (shadow.r.state != Shadow::State::INTAK1));

    // if normal stop, say it's because of stepping
    if (stopreason[0] == 0) {
        stopreason = "SINGLEINSTR";
    }

    ctl_unlock (sigint);

    return true;
}

// wait for stopped
void ctl_wait ()
{
    bool sigint = ctl_lock ();

    while (! (stopflags & SF_STOPPED)) {
        pthread_cond_wait (&stopcond2, &stopmutex);
    }

    if (strcmp (stopreason, "CONTROL_C") == 0) {
        ctrlcflag = false;
    }

    // must be in middle of cycle (clock is high)
    // assumed when we start it back up
    uint32_t sample = gpio->readgpio ();
    ASSERT (sample & G_CLOCK);

    ctl_unlock (sigint);
}
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

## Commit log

2024-02-29 initial release
    [IOW100Paddle.kicad_pcb, IOW100Paddle.sch, IOW56Paddle.kicad_pcb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]
2024-03-04 couple small fixes
    * fix compiler warnings for unchecked syscall return values
    * change default clocking speed so it clocks around 25 kcps average
    * fix driver makefile to build whole.mod and NetGen if needed for -csrclib stuff
    * add -rimloader to raspictl so it can load rim format files
    ./raspictl -rimloader -startpc -0200 CONWAY.RIM
    * add -resetonerr to raspictl so it will reset & restart on error
    - used for testing when varying voltages
    ./raspictl -resetonerr -randmem -mintimes
    * change zynq stuff to use faster clock speed and 6-cell D-flip-flop model
    * add clockfast test program to blindly clock tubes as fast as possible
    [clockfast.cc, csrclib.cc, gpiolib.h]
2024-03-09 patch acl board to fix link clock pulse
    was glitch sized, now half clock cycle sized
    also:
    add zynqlib support to autoboard test
    add individual board selection to zynq implementation
    [gpiolib.h]
2024-03-13 add RESET and LD IF/PC buttons to GUI screen
    also refactor backplane out in zynq so it could be used with de0
    ...but my de0 board is dead
    [GUI.java, GUIRasPiCtl.cc]
2024-03-22 a bunch of small stuff for raspictl
    add run light to GUI
    sync script state changes to GUI
    rename GUI.sh guiraspictl
    loaders return error status instead of aborting
    block sigint when locking haltmutex
    set up halt reason for script to read, don't abort
    check for paddles present instead of aborting if missing
    add help text to some script commands
    have all tty instances able to request interrupt
    script print list of interrupt request sources (iodev memext get)
    make some command-line options available to script (option get)
    give script access to gpio and switchregister
    print tcl stack dump on script error
    print cycle history with script cpu history command
    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
    [GUI.java, GUIRasPiCtl.cc, controls.cc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]
2024-04-02 mostly added dectape plus other changes
    add sizes and trace utilities
    print number of triodes on in raspictl -mintimes
    print number/rates of instructions in raspictl -mintimes
    implement emulated dectape
    - driver/raspictl iodevtty
    - maindec/tc08 d3bc
    - silly/dttest random access test
    - doesn't work with OS/8
    implement using stdin/stdout/pty for ttys
    check for scriptini.tcl file on startup
    add disas and disasop scripting commands to disassemble
    add spvctl circuit board (meanwell spv-300-48 filament slow-start board)
    add some simple scheme programs
    add silly/doubleroll PC/AC light rolling program
    [csrclib.cc, gpiolib.cc, gpiolib.h]
2024-04-08 mostly added dynamic disassembly
    - raspictl tcl script command dyndis
    disassembles based on executing instructions
    other changes:
    raspictl dectape: gofast parameter to eliminate delays
    tty: split debug levels for all io instructions and characters
    memext: ioreset shouldn't reset dframe,iframe (some maindec failed)
    kicads: add project files for processor circuit boards
    maindec: add shell files to run d0ab,d0bb,d0cc,d0db,d0eb tests
    add shell files to run tc08/d3eb
    scheme: fix shift functions to handle nested calls
    simple tictactoe.scm program
    silly: fix dttest.asm dectape test program to seek and read backward
2024-04-25 update manually generated pcbs to include patches and logo
    BACKPLANE 2024-04-17
    EIGHT 2024-04-17
    IOW100PADDLE 2024-04-25
    SPVCTL 2024-04-17
    [IOW100Paddle.kicad_pcb, backplane.kicad_pcb, backplane.kicad_sch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]
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2024-05-11 bunch of stuff
    - fix dynamic disassembly address wrap at end of field
    - optionally optimize ioskip/jmp.-1 to a block in raspi
    - rk8je debug flag, processing rate tcl script accessible
    - rk8je create disk file if not exists
    - rk8je flip sense of BUSY bit
    - rk8je fix dma address wrap at end of field
    - tty add lc->uc translate on input option
    - tty add 8-bit option
    - iow100test just do one paddle at a time and print difference bits
    - allow multiple 'stopat' addresses
    - generalize os8zap to optimize any isz/jmp.-1 loop
    - update kicads to remove old project files
    - add some comments to module files
    - add files for os8 boot
    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
    [eight.kicad_pcb]
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2024-05-27 driver: add some debug prints to try to fix up iodevdtape
2024-05-27 kicads: add missing bwlogo.png file
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2024-05-27 driver: add dumping more boards to tclboardtest
    ...and fix up exam of G_LINK,G_DATA pins
2024-05-27 driver: add a few things to tclboardtest
    - -trace command line option
    - pinof and sigof commands
    - examalua,b commands to tcltestini.tcl
    - pass command-line args to script
    - adapt testit.tcl to use tclboardtest
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2024-05-27 driver: add alu equation to tcltestini dump alu,seq commands
    also add reset and step commands
2024-05-27 driver: use .$(MACH).so instead of .so.$(MACH) for shareables
    also fix netgen makefile to expand jacl141 library
    [csrclib.cc]
2024-05-27 driver: use random bits to initialize csrclib
    ...to be more like tubes on startup
2024-05-31 driver: add -tubesaver option
    feeds random instructions/data to keep tubes cycling during
    HLT and optimized IOSKIP/JMP.-1 instrucitons
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2024-06-02 driver: add resetting to -tubesaver processing
    ...to 'save' the reset circuitry by toggling it
    reset simply sets PC to 0 and state to FETCH1
    [gpiolib.cc, gpiolib.h]
2024-06-02 driver: add testrpiseqboard test program
    it tests combination of rpi and seq boards at full speed
    get rid of bit-rotted testboard program
2024-06-06 kicads: get updated schematics for KiCad 7.0
    IOW100Paddle, eight, spvctl
    [IOW100Paddle.kicad_sch, IOW100Paddle.sch, eight.kicad_sch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]
2024-06-06 driver: fix rtc skip-on-overflow instruction
    also add ioskip/jmp.-1 optimization to rtc
2024-06-06 driver: fix pipelib working with raspictl
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2024-06-14 driver: have autoboard test do resets as part of test
2024-06-14 driver: fix -tubesaver reset cycle in raspictl
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2024-06-14 driver: SCN_EXIT in script mode wakes from wait
    ...instead of exit syscall
2024-06-14 driver: add paddles to nohwlib
    and move readgpio function from shadow to nohwlib
2024-06-23 driver: add -exitonerror and -runtime options to autoboardtest
    ...and have abtevery.sh stop on any error
2024-06-23 zynq: fix gating irq onto bus from seq board
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2024-06-23 driver: add fet1fet2.tcl script
    update tclboardtest to exam all signals at once
2024-06-29 driver: fix up paper tape reader/punch so it works with edu20c basic
    - fix interrupt request
    - add -ascii option when loading files
2024-06-29 driver: add -printfile option for raspictl
    ...to divert -printinstr,-printstate output to a named file
2024-06-29 driver: add -quick option to iodev ptape load command
    ...to speed up edu20c loading
2024-06-30 driver: add -append, punch leader to iodev ptape
    also print message when punch starts, stops
2024-06-30 driver: fix up iodev tty close a little
2024-06-30 driver: fix up focal69 startup script
    and consolidate tubesaver option into scriptini.tcl
2024-07-04 driver: fix up instruction step to stop at INTAK1 as well as FETCH2
    also fix up gui LDADDR/EXAM/DEP/RUN/HALT buttons
    [GUI.java, GUIRasPiCtl.cc, controls.cc]
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2024-07-06 driver: move pidp code so it will work with tubes and simulators
    using simulator on raspi plugged into pidp panel:
    ./raspicctl -pidp [-csrclib/-nohwlib] ...other args
    for tubes, need two raspis:
    one plugged into pidp panel
    ./pidpudpserver.`uname -m`
    one plugged into tubes
    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
2024-07-06 driver: fix nohwlib derivation of mq/mql when QENA=0
    ...should be 0s not 1s
    also fix segment fault on exit with -pidp enabled
    also fix display of stepcounter in pidp leds
2024-07-15 driver: fix rtc to not reset divider chain when getting/setting counter
    also speed up pidp scanning so leds don't look quite as 'samply'
2024-07-17 driver: fix readprompt to work even when stdout is teed
2024-07-17 driver: make reset consistent across interfaces
    make sure if,df get reset in all cases
    no default startpc
    [GUI.java, controls.cc]
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2024-07-22 driver: print ... for skipped-over addresses
2024-07-22 driver: fix dectape support
    - fix debug prints gated by debug setting
    - support ioskipwait optimization
    - update wordcount before writing block number in search so os8 works
    - any error should clear go bit
2024-07-22 driver: fix up paper tape -ascii mode to work better with OS/8
    on punch:
    strip nulls
    strip CRs
    strip control-Z
    zero all bit <7>s
    on read:
    insert leading null
    insert CR before all LFs if not already there
    insert terminating control-Z if not already there
    set all bit <7>s
2024-07-22 driver: fix readprompt prompt when tee-ing stdout
    ...give tee a chance to echo its input
    before prompt gets written to same tty
2024-07-23 driver: format new dectape and decpack files
    puts OS/8 format on newly created dectape and decpack files
2024-07-23 driver: get os/8 dectape to boot
    ...by outputting words very slowly when dma buffer overlaps PC
    also rename dtape stuff to tc08
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2024-07-27 driver: support VC8/I and VC8/E style video displays
    sample programs:
    VC8/I : silly/drawbox.asm
    VC8/E : silly/kaleid.pal
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2024-07-29 driver: speed up -nohwlib simulator
    ABCD was taking a long time to zero the struct in constructor
2024-07-29 driver: vc8 print point draw rate once per minute if -mintimes option
2024-07-29 silly: cycle through shift counts automatically in kaleid
    ...and update MQ,SC leds in case of PiDP panel
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2024-07-31 driver: remove cpu affinity for all but main thread
    main thread uses cpu affinity when using a timestamp counter for
    rdcyc() so the count will be consistent, but device and other
    threads don't need the affinity cuz they don't use rdcyc()
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2024-08-04 driver: get dectape MAINDEC D3EB test to run
    cd maindec/tc08
    ./rund3ra.sh
    monitor dectape operation on another screen:
    cd drivers
    ./tc08status
2024-08-09 driver: add iodev tty halton & inject commands for writing test scripts
    halton halts processor when one of the given strings is seen on tty output
    inject injects characters into keyboard stream
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2024-08-09 driver: consolidate creating threads
    main thread calls rdcyc() that reads the cpu-specific timestamp counter
    for software timing loops to control the clock going to the tubes, so
    the main thread is restricted to cpu #1 so the same timestamp counter is
    used throughout.
    the other threads can use any cpu, so use pthread attributes to create
    them with all cpus enabled.
    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
2024-08-15 driver: fix tty inject to work even kb directed to /dev/null
2024-08-15 driver: simplify csrclib so it just uses csrcmod_proc
    ...and not need csrcmod_<everypossiblecombinationofboards>
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2024-08-20 driver: unload dectape if left turned on for 5 seconds
    ...without doing any I/O, to simulate winding off spool
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2024-08-20 driver: separate out stopping from halting
    stopping - commanded by gui or script
    halting - HLT instruction (or optimized IOSKIP/JMP.-1)
2024-08-21 driver: follow-up fixes for halt/stop stuff
    * fix script haltstop option
    * put stuff renamed halt->stop in alphabetic order
    * change tubesaver to use reset to restore state
    instead of waiting for a fetch2 cycle
2024-08-22 driver: add -echo option to tty inject command
    waits for each character to be echoed before injecting next
2024-08-22 driver: get rid of bit-rotted obsolete iodevrk8
    OS/8 uses iodevrk8je for RK05s
2024-08-22 maindec: modernize maindec run scripts
    cd maindec
    ./run_<testname>.sh <option>
    option = none to run on tubes
    -csrclib : use gate-level PC simulator (medium)
    -nohwlib : use cycle-level PC simulator (fast)
    -zynqlib : use zynq fpga simulator at tube speed
    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
2024-08-23 driver: fix makefile for FixCSrcModProc.java
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2024-08-25 driver: display changed VC8 screen size in upper left corner
    also check VC8 max screen size so it doesn't crash
2024-08-25 driver: avoid hanging on control-C or other terminating signal
    call exit() from a thread other than main() in case main() has
    a mutex locked and exithandler() locks a mutex that main() has
2024-08-28 driver: clean up control-C with scripts
    set stopreason to CONTROL_C
    two control-Cs in a row force exit
2024-09-02 driver: have stops/steps stop in middle of cycle with clock high
    simplifies some things
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2024-09-24 driver: finish up HLT/WFI differentiation
    fix comments and rename some things
    [controls.cc]
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2024-09-24 driver: suppress control-C while reading from keyboard
    ...so double control-C won't abort the program
2024-09-24 driver: fix -randmem halting
2024-09-24 driver: fix loadmod.sh if it needs to load 2 modules
    ...like for zynq
2024-09-30 zynq: add missing zynq file myboard_wrapper.vhd
    also fix up makentov.sh script that creates <boardname>_nto.v files
    and update howto-build.txt
2024-09-30 driver: adapt zynqlib to connect to pipanel via i2c
    ...but zynq gets timeout error writing to /dev/i2c-0
    don't see any i2c scl with the ila probe
    uses pdp8l/pipanel/i2c pipanel program running on zynq
    to connect to via /dev/i2c-0, but it gets timeout error
    [csrclib.cc, gpiolib.cc, gpiolib.h]
2024-09-30 driver: preserve AC,LINK across continue switch from zynq i2c panel
    passes ac,link to ResetProcessorException which then loads them when caught
    [controls.cc]
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2024-09-30 zynq: swap frontpanel.v MCP23017 A<->B pins to match actual PCB
2024-10-01 zynq: attempt to get zynq's /dev/i2c-0 to talk to frontpanel
    ...gets occasional timeout errors
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2024-12-02 driver: fix ptape reader busy/idle messages
2025-10-12 add back panel librecad drawing
    holds (4) filament power supplies
    (2) high-voltage power supplies
    (1) 5V power supply
    (5) 2-prong AC outlets for fans
    (2) 3-prong AC inlets for power cords
    (1) 3-prong AC outlet for test equipment
    also fixed notitlepage references in some kicad files
2025-10-17 fix backpanel hole sizes
    - fan outlets should be 1/2" wide not 3/8"
    - 5V power supply screw holes 66.5mm not 55mm apart
2025-11-29 fix backplane shorted VPP connector by ground pad
    protection diode cathode was shorted to ground
    also turn filament connectors 90 degrees for easier wiring
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2026-10-04 fix pidp panel interface
    also works with pdp8i project's realpanel board
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2026-10-23 fix pidp panel load address switch

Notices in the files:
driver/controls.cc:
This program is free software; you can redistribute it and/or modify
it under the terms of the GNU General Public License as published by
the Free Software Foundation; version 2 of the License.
